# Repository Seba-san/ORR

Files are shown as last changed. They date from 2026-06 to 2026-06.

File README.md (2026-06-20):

# 🌐 Outdoor Radio Robotics (ORR)

> **Módem digital AFSK de código abierto para telemetría robótica sobre transceptores analógicos VHF/UHF en entornos agrícolas con alta densidad de follaje.**

Este repositorio contiene el diseño de *hardware*, el *firmware* embebido y la suite de procesamiento digital de señales de la plataforma **ORR** (*Outdoor Radio Robotics*). El sistema ha sido desarrollado en el **Instituto de Automática (INAUT)** de la **Universidad Nacional de San Juan (UNSJ)** y sirve como material complementario y de validación experimental para posibilitar una comunicación digital de enjambres robóticos e instrumentación en agricultura de precisión.

---

## 📝 Descripción del Proyecto

El despliegue de plataformas robóticas autónomas en entornos agrícolas reales (como olivares o viñedos) enfrenta atenuación electromagnética en las bandas tradicionales de $2.4\text{ GHz}$ o $5.8\text{ GHz}$ debido a la absorción por la biomasa y el follaje húmedo. Para sortear esta limitación física, el proyecto **ORR** propone una arquitectura de acoplamiento no intrusiva que convierte transceptores analógicos de FM comerciales (como el **Baofeng UV-82**) en radio-módems digitales de datos en las bandas de VHF/UHF.

<p align="center">
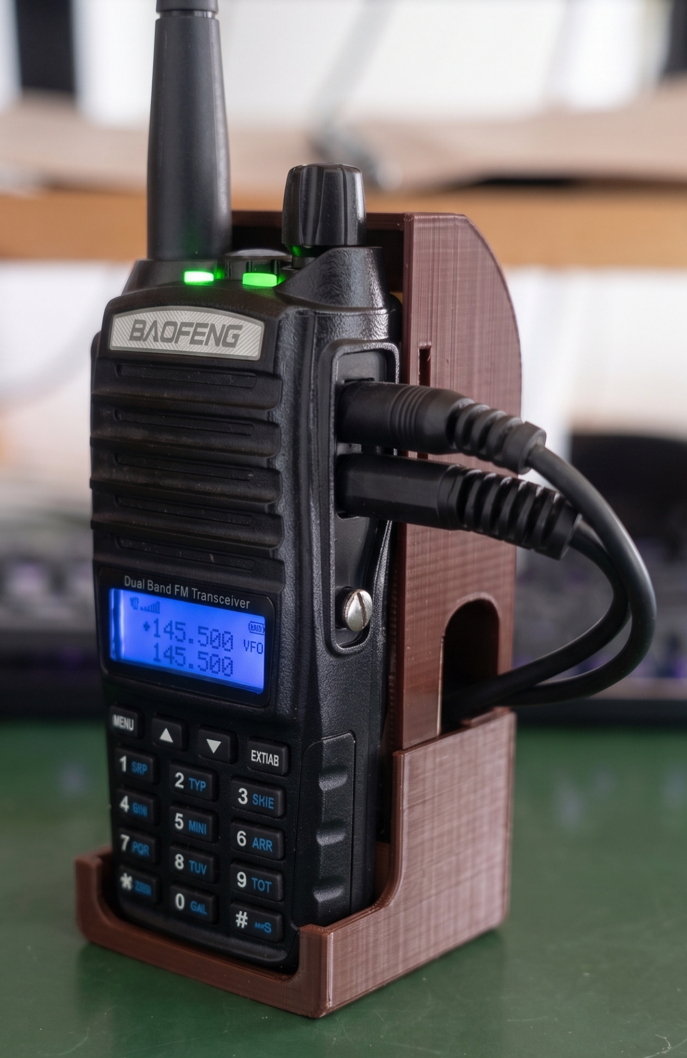
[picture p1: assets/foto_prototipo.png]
Prototipo de radio-módem digital acoplado a transceptor analógico
  
</p>

Mediante el uso de un microcontrolador (**Raspberry Pi Pico 2W**), se implementa un módem AFSK (*Audio Frequency Shift Keying*) a velocidades de hasta 1200 baudios. El sistema se comporta como un bloque físico autónomo que reduce los costos de equipamiento en más de dos órdenes de magnitud respecto a transceptores tácticos industriales.

<p align="center">
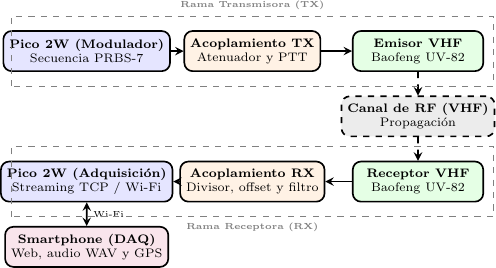
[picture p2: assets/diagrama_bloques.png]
Diagrama de bloques de la arquitectura del sistema ORR
  
</p>

---

## 🛠️ Características Principales

### 1. Acondicionamiento Analógico de *Hardware*
* **Alimentación Unificada:** El microcontrolador se alimenta directamente de la batería de Li-ion del transceptor (7.4 V nominales) mediante un regulador lineal de bajo descarte (LDO), eliminando fuentes de energía secundarias.
* **Aislamiento Galvánico:** Se implementa un aislamiento en la línea de control de transmisión PTT (*Push-To-Talk*) mediante un optoacoplador PC817. Las líneas de audio analógicas emplean un acople AC capacitivo y divisores de tensión específicos para evitar la saturación del amplificador de la radio y proteger las entradas del ADC de la placa Pico 2W.
* **Prevención de Bucles de Masa:** Las masas analógicas y digitales se aíslan en el diseño del conector *jack* de audio, suprimiendo ruidos de conmutación electromagnética que degradarían la relación señal-ruido (SNR).

### 2. Gabinete Mecánico Impreso en 3D
* **Diseño Protector:** Carcasa diseñada para impresión 3D en PLA o PETG que protege la electrónica discreta contra las vibraciones de la maquinaria agrícola.
* **Encastre Antieyección:** Estructura con ranuras específicas que aseguran físicamente el pestillo de liberación de la batería de la radio, previniendo desconexiones accidentales durante el trabajo de campo.

### 3. *Firmware* Embebido (MicroPython)
* **Lazo de Transmisión *Zero-Allocation*:** Síntesis DDS (*Direct Digital Synthesis*) de tonos mediante una tabla de búsqueda (LUT) senoidal precomputada mapeada a PWM de *hardware* a 125 kHz.
* **Supresión de *Jitter*:** Durante la transmisión de tramas (patrones pseudoaleatorios PRBS-7), el recolector de basura (*garbage collector*) se deshabilita temporalmente con `gc.disable()`, asegurando un flujo libre de derivas temporales no deterministas.
* **Protección Térmica Activa:** Máquina de estados finitos que limita la transmisión continua a un máximo de 30 segundos, forzando un ciclo de enfriamiento pasivo equivalente para prolongar la vida útil del paso final de potencia RF de la radio.
* *****Streaming*** Asíncrono Multilazo:** Lectura en tiempo real del ADC a 19.2 kHz mediante *buffers* dobles (*ping-pong*) en el *Core* 1 de la Pico 2W, mientras que el *Core* 0 gestiona un servidor TCP *socket* embebido sobre Wi-Fi para transmitir los datos de forma inalámbrica a la base del operador.

### 4. Demodulador por Envolventes Balanceadas
* **Pipeline Bifurcado por Velocidad:** El pipeline de demodulación se adapta al régimen de baudios detectado.
  - **1200 bd:** Usa filtros `filtfilt` de **fase nula** (*zero-phase*) en las etapas de pasa-banda y pasa-bajos de envolvente, eliminando el retardo de grupo de ~8.8 muestras que causaba ISI sistemático con el método causal clásico. La señal resultante se normaliza geométricamente al rango $[-1, +1]$ usando el punto medio entre percentil 5 y 95 del burst activo, y se aplica un squelch de inicio para evitar el falso enganche del reloj (*false lock*) sobre silencios previos a la ráfaga.
  - **≤ 600 bd:** Usa filtros causales clásicos (`lfilter`), donde el retardo de grupo es despreciable en proporción al período de símbolo.
* **Demodulación por Envolventes Balanceadas:** En ambos casos, las envolventes de amplitud de Mark y Space se compensan con un factor de ganancia dinámica $g$ calculado sobre los percentiles de amplitud del segmento activo: $y = env_{\text{mark}} - g \cdot env_{\text{space}}$.
* **Sincronización DPLL con Grilla Configurable:** La búsqueda de la fase de ráfaga se realiza en una ventana de $1 \times N_s$ muestras (hasta $15 \times N_s$ para 1200 bd), seguida de la sintonización automática del DPLL por grilla sobre los candidatos $K_p$ y $K_i$ definidos en `modules/config.py`. El período de símbolo $N_s = f_s / \text{baud}$ se calcula siempre dinámicamente, sin valores fijos por velocidad.
* **Métrica de Confianza ($C_k$):** Cálculo analítico de la diferencia relativa entre las envolventes balanceadas de Mark y Space en cada instante de muestreo, lo que permite evaluar la calidad del bit recuperado directamente en la etapa de decisión.

---

## 📈 Ensayos y Resultados Experimentales

Para validar el desempeño del módem AFSK y el enlace de radiofrecuencia en condiciones de operación reales, se diseñó y ejecutó una campaña experimental dividida en **dos entornos de ensayo diferenciados** (2 experimentos independientes):

1. **Espacio Abierto (Libre):** Ensayo en línea de vista rural libre de obstáculos y follaje. Sirve como canal de calibración y referencia para evaluar el desempeño básico y el límite térmico/frecuencial del enlace.
2. **Bajo Follaje de Olivos (Campo):** Ensayo realizado en una plantación densa de olivos en la provincia de San Juan, Argentina. El enlace se caracterizó por la total obstrucción de la línea de vista directa debido a la biomasa frutal, con las radios posicionadas a menos de 1 metro del suelo y las antenas polarizadas horizontalmente para evitar la absorción de los troncos verticales.

Ambos experimentos operaron a una potencia de **1.0 W** (Low Power) en la banda UHF a **433 MHz**.

### 1. Entornos de Ensayo

La siguiente ilustración muestra las condiciones físicas de ambos escenarios de medición:

<p align="center">
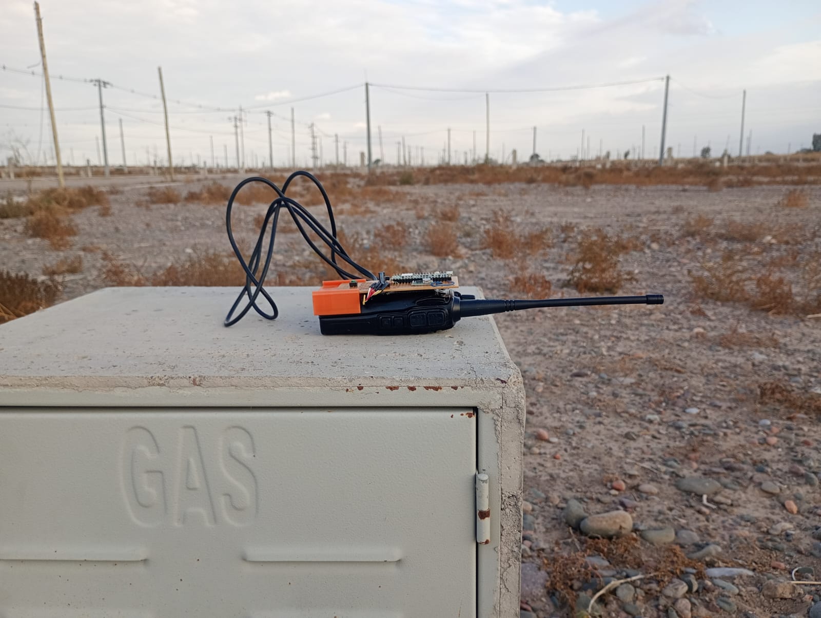
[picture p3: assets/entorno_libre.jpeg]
Entorno del ensayo en espacio abierto (Libre)
  
  Entorno del ensayo bajo follaje de olivos (Campo)
</p>

### 2. Georreferenciación de Mediciones (Figura 5 del Paper)

Los puntos específicos de medición, capturados y georreferenciados mediante el Web-DAQ en el teléfono celular del operador, se ubican a distancias nominales de **5 m, 500 m, 1000 m y 1500 m** en la plantación:

<p align="center">
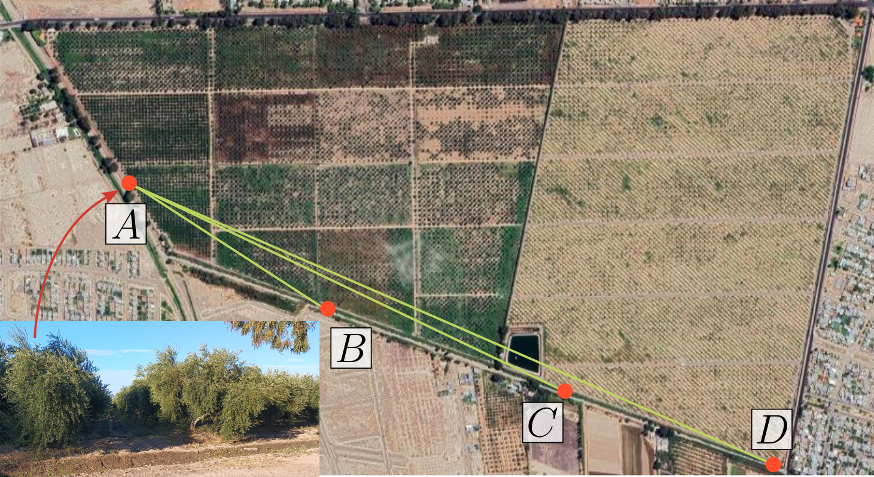
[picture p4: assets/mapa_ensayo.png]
Mapa de puntos de ensayo y geolocalización de las mediciones
  
</p>

### 3. Tasa de Error de Bit (BER)

A continuación se consolidan los resultados de la Tasa de Error de Bit (BER %) obtenidos en cada entorno para las diferentes distancias reales y regímenes de velocidad (baudrate) analizados:

#### Experimento 1: Espacio Abierto (Libre)
| Distancia Real (Nominal) | 10 bd | 50 bd | 150 bd | 300 bd | 600 bd | 1200 bd |
| :---: | :---: | :---: | :---: | :---: | :---: | :---: |
| **0 m** (5 m) | 0.00% | 0.00% | 0.36% | 0.03% | 0.06% | 5.39% |
| **552 m** (500 m) | 0.00% | 0.08% | 0.05% | 0.04% | 0.06% | 5.80% |
| **985 m** (1000 m) | 0.00% | 0.08% | 0.02% | 0.04% | 0.13% | 11.20% |
| **1382 m** (1500 m) | 0.00% | 0.04% | 0.06% | 0.02% | 0.06% | 5.80% |

#### Experimento 2: Bajo Follaje de Olivos (Campo)
| Distancia Real (Nominal) | 10 bd | 50 bd | 150 bd | 300 bd | 600 bd | 1200 bd |
| :---: | :---: | :---: | :---: | :---: | :---: | :---: |
| **0 m** (5 m) | 0.00% | 4.69% | 0.08% | 0.03% | 0.05% | 5.49% |
| **549 m** (500 m) | 0.00% | 0.04% | 0.05% | 0.04% | 0.51% | 5.40% |
| **1071 m** (1000 m) | 0.00% | 0.00% | 0.03% | 0.05% | 0.06% | 5.46% |
| **1484 m** (1500 m) | 0.00% | 0.04% | 0.03% | 0.02% | 0.03% | 6.33% |

El comportamiento y la comparación visual del BER de ambos entornos se detalla en las curvas experimentales (subplots) obtenidas:

<p align="center">
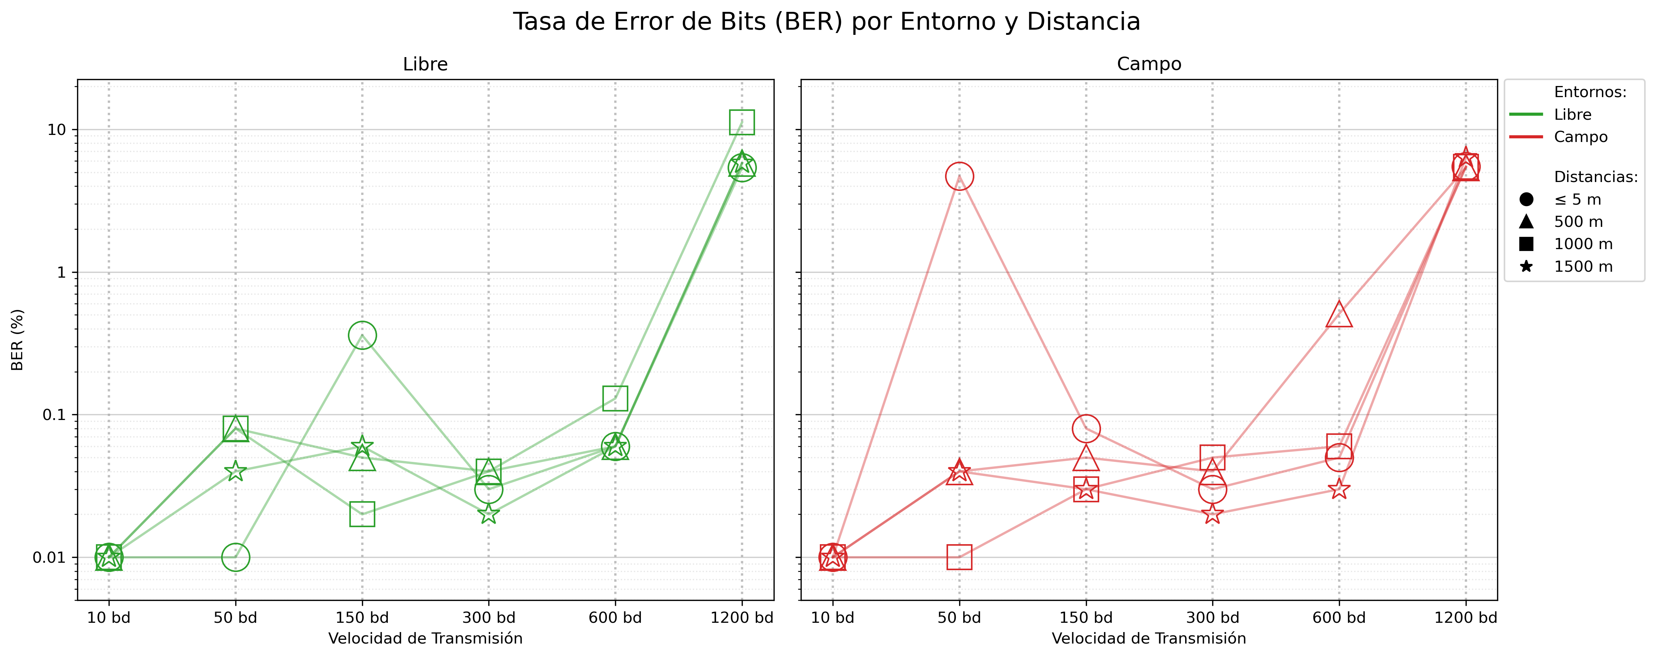
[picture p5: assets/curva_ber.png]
Curvas experimentales de tasa de errores de bit (BER) vs velocidad y distancia
  
</p>

---

## 💾 Dataset Experimental y Bases de Datos

Las campañas de medición en campo y laboratorio produjeron un conjunto de datos (*dataset*) de señales de audio digitalizadas y telemetría de geolocalización. Debido al volumen y al tamaño de los archivos de audio crudos (`.wav`), el dataset completo está almacenado en un repositorio compartido externo.

* 🔗 **Acceso al Dataset Completo (Google Drive):** [Bases de Datos de Audio ORR](https://drive.google.com/drive/folders/1wKw8cH1Ox6S6E19gmR8-GltFr6CDUwmw?usp=sharing)
* 📖 **Descripción Detallada:** Para una explicación completa sobre la secuencia pseudoaleatoria PRBS-7, el hardware de adquisición Web-DAQ (Core 1 para ADC y Core 0 para Wi-Fi/streaming), las velocidades ensayadas, el significado de los nombres de los archivos y la distribución de las carpetas, consulte la [Guía Detallada del Dataset](./data/README.md).

---

## 📂 Estructura de Directorios

El repositorio se organiza de la siguiente manera:

```
ORR/
├── assets/              # Imágenes y recursos visuales para la documentación
├── data/                # Dataset experimental (archivos CSV con metadatos GPS e instruciones de audio)
├── firmware/            # Código fuente para Raspberry Pi Pico 2W (MicroPython)
│   ├── tx/              # Firmware del nodo transmisor (DDS, PWM, FSM, PRBS-7)
│   └── rx/              # Firmware del nodo receptor (adquisición en Core 1, servidor TCP en Core 0)
├── fotos/               # Fotografías de los entornos experimentales (libre y campo)
├── hardware/            # Esquemáticos y manual de acondicionamiento de la interfaz analógica
│   └── esquematicos/    # Circuitos y pinout de interconexión
├── mechanics/           # Gabinete protector e interfaz de acople mecánico 3D (STL/STEP)
└── processing/          # Suite de demodulación *offline* en Python (Envolventes, Búsqueda de Fase, BER) y MATLAB
```

---

## 🚀 Cómo Empezar

### Requisitos Previos
* ***Hardware***:
  * Raspberry Pi Pico 2W (o Pico W estándar).
  * Transceptor analógico FM Baofeng UV-82 (o similar con conector tipo Kenwood de dos pines).
  * Componentes discretos detallados en los esquemáticos de la carpeta `hardware/`.
* **Software:**
  * MicroPython v1.20 o superior instalado en el microcontrolador.
  * Suite de demodulación: Python 3.10+ con las librerías indicadas en [processing/requirements.txt](./processing/requirements.txt).

Para instrucciones detalladas de implementación de cada módulo, por favor consulta los archivos `README.md` y guías específicos dentro de cada directorio:
* Ver [firmware/README.md](./firmware/README.md) para la configuración del microcontrolador.
* Ver [hardware/README.md](./hardware/README.md) para el circuito de acoplamiento analógico.
* Ver [processing/README.md](./processing/README.md) para la suite de demodulación espectral y cálculo de BER.
* Ver [processing/workflow_bursts.md](./processing/workflow_bursts.md) para el flujo de trabajo integrado y segmentación automática de ráfagas.
* Ver [data/README.md](./data/README.md) para acceder a los metadatos de GPS y descargar el dataset de audio.

---

## 🎓 Créditos y Citación

Este desarrollo forma parte de la línea de investigación en redes tolerantes a retardos (DTN) aplicadas a la robótica agrícola del **INAUT (UNSJ)**.

Si utiliza este trabajo en su investigación o desarrollo, por favor cite el artículo científico asociado:

```bibtex
@inproceedings{sansoni2026orr,
  author    = {Sansoni, Sebastian},
  title     = {Diseño y Análisis de un sistema de Comunicación Digital sobre Radios Analógicas para Robótica en exteriores},
  booktitle = {Actas de las Jornadas Argentinas de Robótica (JAR)},
  year      = {2026},
  address   = {San Juan, Argentina}
}
```

---

## ⚖️ Licencia

Este proyecto está bajo la licencia **Apache 2.0**. Esto significa que es **código abierto** y libre para cualquier uso (incluyendo comercial, modificación y distribución), con las siguientes garantías clave:
* **Protección de Patentes:** Evita litigios de patentes entre colaboradores y usuarios.
* **Respeto de Marca:** Protege el nombre del proyecto (*Outdoor Radio Robotics*) e institucional (INAUT/UNSJ) frente a usos no autorizados de terceros en software derivado.

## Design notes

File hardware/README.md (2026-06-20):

# 🛠️ Acondicionamiento Analógico y Hardware (Front-End)

El acoplamiento físico entre la Raspberry Pi Pico 2W y la radio analógica **Baofeng UV-82** se realiza de forma externa y no intrusiva a través del conector tipo Kenwood de 2 pines (*jack* de 3.5 mm para audio/parlante y *jack* de 2.5 mm para micrófono/PTT). 

Este directorio recopila las especificaciones de diseño, cálculos analógicos y diagramas esquemáticos para reproducir la interfaz física.

---

## 📌 Conector Kenwood y Distribución de Colores

Para evitar falsos contactos y ruidos analógicos inducidos por soldaduras deficientes, se utiliza un cable comercial premoldeado Kenwood cortado a la mitad. Los colores internos del conductor típicamente corresponden a las siguientes conexiones:

```
               [ PLUG 3.5 mm ]                     [ PLUG 2.5 mm ]
               (Parlante / RX)                     (Micrófono / TX)
               
                 .-.                                 .-.
                |   | Punta (Rojo): +Speaker        |   | Punta (Rojo): -Mic / PTT1
                |===|                               |===|
                |   | Anillo (Amarillo): Tx Data    |   | Anillo (Amarillo): +Mic
                |===|                               |===|
                |   | Base (Blanco): GND/Shield     |   | Base (Blanco): GND/PTT Base
                `---'                               `---'
```

---

## 📻 1. Circuito de Transmisión (Front-End TX) y Control PTT

El circuito transmisor acondiciona la señal digital de audio generada por PWM del microcontrolador y gobierna el pulsador *Push-To-Talk* (PTT) de la radio mediante aislamiento óptico.

### Diagrama Esquemático

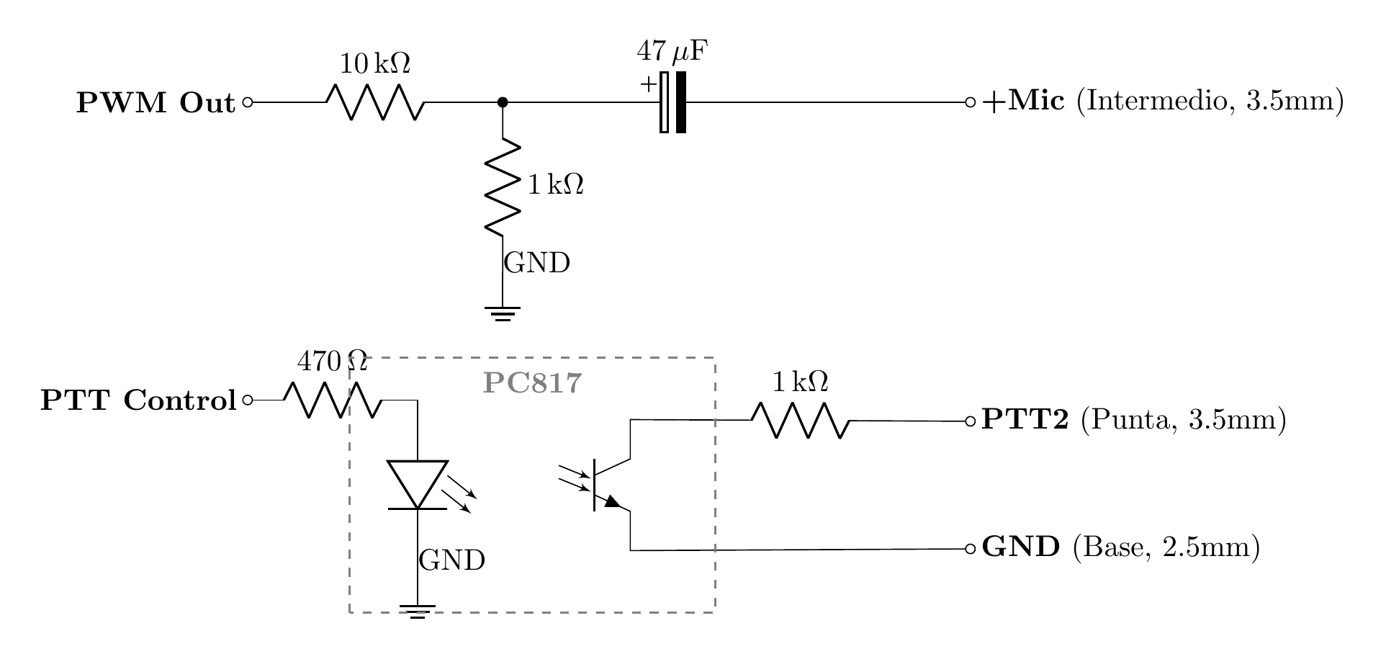
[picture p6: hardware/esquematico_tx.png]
Esquema de acondicionamiento de transmisión (TX) y aislamiento galvánico de la línea PTT


### Explicación del Diseño y Cálculos
1. **Atenuación Resistiva (Divisor L):** La señal PWM sintetizada por el pin `GP17` oscila en un rango digital de 0 a 3.3 V pico a pico. Para no saturar el amplificador de entrada de micrófono de la radio (diseñado para niveles de voz de ~10-30 mV), el divisor resistivo ($R_1 = 10\text{ k}\Omega$, $R_2 = 1\text{ k}\Omega$) atenúa la señal en un factor de:
   $$Av = \frac{R_2}{R_1 + R_2} = \frac{1\text{ k}\Omega}{10\text{ k}\Omega + 1\text{ k}\Omega} \approx 0.091\text{ (i.e., } -20.8\text{ dB)}$$
   Esto reduce la señal a $\approx 300\text{ mV}_{\text{p-p}}$ en el nodo intermedio, previniendo recortes armónicos.
2. **Bloqueo de Tensión Continua (C1):** Un capacitor electrolítico de $47\,\mu\text{F}$ en serie bloquea la componente continua de la Pico 2W. Junto con la impedancia de entrada de la radio ($R_{\text{mic}} \approx 2\text{ k}\Omega$), forma un filtro paso alto con frecuencia de corte:
   $$f_c = \frac{1}{2\pi R_{\text{mic}} C_1} = \frac{1}{2\pi \cdot 2000\,\Omega \cdot 47\,\mu\text{F}} \approx 1.69\text{ Hz}$$
   Esto asegura una respuesta plana para las frecuencias de audio AFSK ($1200\text{ Hz}$ y $2400\text{ Hz}$).
3. **Aislamiento Galvánico del PTT:** Para transmitir, la radio requiere unir físicamente la línea de micrófono con masa. Para no cortocircuitar o introducir ruido del plano digital del microcontrolador al transmisor de RF, se implementa un optoacoplador **PC817**. El pin digital `GP16` enciende el LED interno (limitado por $R_3 = 470\,\Omega$), el cual satura el fototransistor interno para cerrar el circuito PTT de la radio de forma aislada.

---

## 🎧 2. Circuito de Recepción (Front-End RX)

El circuito adaptador del receptor reduce los altos niveles de tensión del altavoz analógico de la radio y los centra en el rango dinámico unipolar (0 a 3.3 V) de la entrada analógica `GP26 (ADC0)` del microcontrolador.

### Diagrama Esquemático

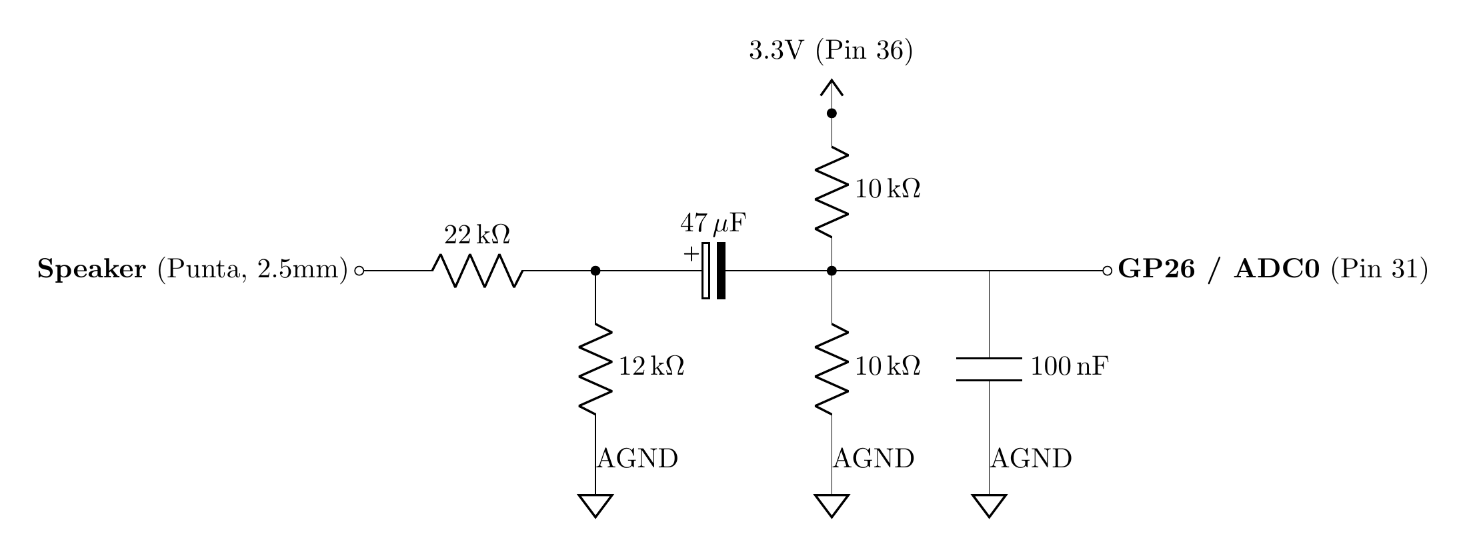
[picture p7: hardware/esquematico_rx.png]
Esquema del Front-End Analógico de Recepción


### Explicación del Diseño y Cálculos
1. **Atenuador de Entrada (R4, R5):** El volumen máximo de salida del altavoz de la radio puede superar los 5 V pico a pico, lo que dañaría la entrada del ADC. El divisor compuesto por $R_4 = 22\text{ k}\Omega$ y $R_5 = 12\text{ k}\Omega$ atenúa la señal analógica multiplicándola por un factor de $0.35$ ($\approx 1.76\text{ V}_{\text{p-p}}$ máximo), garantizando un margen seguro.
2. **Acoplamiento AC (C2):** Un capacitor electrolítico de $47\,\mu\text{F}$ en serie elimina el nivel de continua original de la etapa amplificadora de audio de la radio.
   * La resistencia de fuente equivalente es $R_s = R_4 \parallel R_5 \approx 7.76\text{ k}\Omega$.
   * La resistencia de polarización es $R_{\text{bias}} = R_6 \parallel R_7 = 5\text{ k}\Omega$.
   * La frecuencia de corte del filtro paso alto resultante es:
     $$f_c = \frac{1}{2\pi (R_s + R_{\text{bias}}) C_2} = \frac{1}{2\pi \cdot (7760\,\Omega + 5000\,\Omega) \cdot 47\,\mu\text{F}} \approx 0.265\text{ Hz}$$
     Esta frecuencia de corte garantiza que la señal analógica entre al ADC libre de distorsiones de fase temporales.
3. **Red de **Offset** (R6, R7):** El ADC de la Pico lee tensiones de $0$ a $3.3\text{ V}$. Para poder digitalizar el semiciclo negativo de la onda senoidal de audio sin recorte, el divisor resistivo simétrico de dos resistencias de $10\text{ k}\Omega$ inyecta un desplazamiento continuo de exactamente **$1.65\text{ V}$** (mitad del rango del ADC).
4. **Filtro de Ruido de Referencia (C3):** Un capacitor cerámico de $100\text{ nF}$ en paralelo con $R_7$ desacopla armónicos de alta frecuencia y ruidos de conmutación del bus digital de alimentación de 3.3 V, estabilizando la referencia analógica del ADC.

---

## ⚠️ Advertencia Crítica de Bucles de Tierra

> [!CAUTION]
> **COMPARTIR BATERÍA EXIGE MASA DE AUDIO AISLADA:**
> Si la Raspberry Pi Pico 2W y la radio Baofeng UV-82 se alimentan unificadamente de la misma batería (7.4 V de la radio adaptados a la Pico), ambos equipos ya poseen una referencia común a través de la masa de alimentación. 
> 
> En esta condición, **bajo ningún concepto se debe soldar el cable de masa del *jack* de 3.5 mm / 2.5 mm a la masa digital (GND) del microcontrolador**. Si se realiza esta conexión secundaria, se cierra un lazo inductivo que reduce la relación señal-ruido (SNR) del ADC e introduce un zumbido de clicks en el audio analógico, aumentando la tasa de errores de bit (BER).

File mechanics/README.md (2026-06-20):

# 🖨️ Gabinete Mecánico 3D y Acoplamiento

Este directorio está reservado para los modelos tridimensionales (archivos `.stl`, `.step` / `.stp`) de la carcasa de protección y acople mecánico del módem ORR con la radio Baofeng UV-82.

---

## 🛠️ Características de Diseño

El diseño del gabinete ha sido desarrollado considerando las condiciones de vibración y humedad del trabajo agrícola en el campo:

1. **Dimensiones Extendidas:** La carcasa se ha alargado físicamente para alojar de forma holgada tanto la placa transmisora (TX) como la receptora (RX) con sus componentes discretos. Esto evita tensiones mecánicas internas o desprendimiento de soldaduras.
2. **Protector de Pestillo de Batería:** Se integran encastres y ranuras protectoras para el botón de liberación de la batería del Baofeng UV-82. Esto previene que el módulo digital presione accidentalmente el mecanismo de eyección y provoque que la batería se desprenda ante sacudidas o golpes en tractores agrícolas.
3. **Puntos de Alivio de Tensión:** Cuenta con pasacables con curvas diseñadas para evitar fatiga en los conectores de audio de 3.5 mm y 2.5 mm.

---

## ⚙️ Parámetros de Impresión Recomendados

Para garantizar la durabilidad a la intemperie y resistencia a la radiación solar en cultivos agrícolas, se sugieren los siguientes parámetros:

* **Material:** **PLA** o **PETG** (seleccionados de acuerdo a la facilidad de impresión y la tolerancia térmica requerida).
* **Altura de Capa:** $0.2\text{ mm}$ o $0.15\text{ mm}$ para un encastre preciso.
* **Relleno (Infill):** $25\text{ a } 35\%$ con patrón giroidal (*gyroid*) o rejilla para maximizar la resistencia a impactos.
* **Perímetros (Muros):** Mínimo 3 de espesor.
* **Soportes:** No requiere soportes si se orienta de forma plana sobre la base (según el diseño de encastres).

---

## 📂 Archivos de Diseño 3D en esta carpeta

Este directorio contiene las piezas del diseño final de la carcasa, listas para imprimir o editar:

*   **[base_v4-carcasa.stl](./base_v4-carcasa.stl)**: Pieza principal del gabinete de protección (carcasa).
*   **[base_v3-base_con_placa.stl](./base_v3-base_con_placa.stl)**: Base de acoplamiento que sostiene mecánicamente la electrónica y las placas.
*   **[lengueta.stl](./lengueta.stl)**: Pestillo o lengüeta de traba para fijar el ensamble al seguro de la radio.
*   **[base_v4.FCStd](./base_v4.FCStd)**: Archivo de diseño paramétrico original creado en **FreeCAD** (herramienta de CAD de código abierto). Contiene todo el historial de modelado para realizar modificaciones, redimensionados o adaptaciones futuras.

---

## 📷 Previsualización del Ensamble y Piezas

A continuación se muestran capturas de pantalla de los modelos mecánicos exportados directamente desde **FreeCAD** para facilitar la comprensión de las piezas y el ensamble final con la radio:

| Ensamble Completo con Radio | Ensamble de Piezas de Carcasa |
| :---: | :---: |
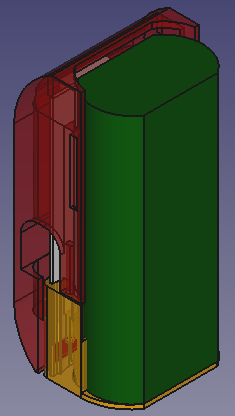
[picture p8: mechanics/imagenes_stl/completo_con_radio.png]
Ensamble Completo con Radio Baofeng
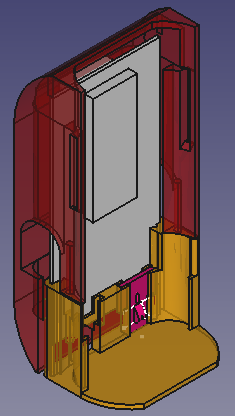
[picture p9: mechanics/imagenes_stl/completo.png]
Ensamble de la Carcasa Cerrada
|  |  |
| **Placa Base y Lengüeta de Traba** | |
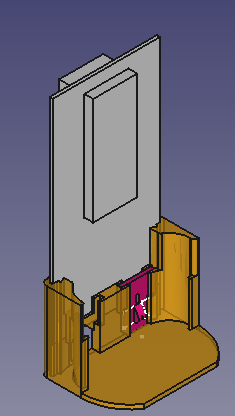
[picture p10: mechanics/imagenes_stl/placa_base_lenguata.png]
Placa Base y Lengüeta
|  | |

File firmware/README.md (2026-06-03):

# 💾 Firmware Embebido: Módem AFSK para Raspberry Pi Pico 2W

Esta carpeta contiene el firmware en **MicroPython** desarrollado para los nodos Transmisor (TX) y Receptor (RX) del sistema de comunicación digital ORR, ejecutados en microcontroladores Raspberry Pi Pico 2W (basados en el chip RP2350).

---

## 🛠️ Requisitos Previos e Instalación

### 1. Cargar MicroPython
Ambos microcontroladores deben tener instalado **MicroPython v1.20** o superior.
1. Descarga el firmware oficial `.uf2` para la Raspberry Pi Pico 2W/W desde [micropython.org](https://micropython.org/download/RPI_PICO2W/).
2. Conecta la placa a la computadora por USB manteniendo presionado el botón **BOOTSEL**.
3. Suelta el botón una vez que la placa aparezca como una unidad de almacenamiento masivo llamada `RPI-RP2` (o similar).
4. Arrastra y suelta el archivo `.uf2` dentro de la unidad. El dispositivo se reiniciará automáticamente corriendo MicroPython.

### 2. Cargar los Archivos
Utiliza un IDE compatible como **Thonny** o herramientas de línea de comandos como `mpremote` para transferir los archivos:
* **Para el Transmisor:** Carga todos los archivos de la carpeta [tx/](./tx) en la raíz de la memoria flash del microcontrolador.
* **Para el Receptor:** Carga todos los archivos de la carpeta [rx/](./rx) en la raíz de la memoria flash del microcontrolador.

---

## 📌 Mapeo de Pines de la Raspberry Pi Pico 2W

Las interfaces se han estandarizado sobre las siguientes conexiones físicas de la placa:

| Pin Físico | Pin Lógico | Función en el Sistema | Conexión Externa Asociada |
| :---: | :---: | :--- | :--- |
| **Pin 4** | `GP2` | Entrada Digital (Pulsador) | Pulsador de activación (Gatillo) a tierra (`GND`) |
| **Pin 22** | `GP17` | Salida de Audio PWM (TX) | Entrada al Atenuador analógico de Transmisión (Mic) |
| **Pin 21** | `GP16` | Control Digital PTT | Entrada del Optoacoplador PC817 (Pin 1 - Ánodo) |
| **Pin 23** | `GND` | Tierra Digital | Entrada del Optoacoplador PC817 (Pin 2 - Cátodo) |
| **Pin 31** | `GP26` | Entrada de Adquisición ADC (RX) | Salida del circuito Front-End Analógico (AFE) |
| **Pin 33** | `AGND` | Tierra Analógica | Referencia del circuito Front-End Analógico (AFE) |
| **Pin 36** | `3V3_OUT` | Alimentación de Referencia | Red de polarización resistiva del Front-End (Offset) |

> [!WARNING]
> **PREVENCIÓN DE BUCLES DE TIERRA:**
> Al compartir la alimentación directa de la batería del transceptor, el microcontrolador y la radio poseen una referencia de masa común. Por lo tanto, **bajo ningún concepto se debe conectar el pin de masa (GND) del conector *jack* de audio a la masa digital de la placa Pico 2W**. De realizar esta conexión secundaria, se creará un bucle de tierra cerrado inductivo que inyectará zumbidos electromagnéticos en el receptor, aumentando la tasa de errores de bit y pudiendo ocasionar daños físicos por corrientes de retorno de RF.

---

## 🚀 Instrucciones de Operación

### 1. Transmisor (TX)
El firmware del transmisor sintetiza tonos AFSK puros mediante el periférico PWM por hardware a 125 kHz utilizando una tabla de búsqueda senoidal de 256 muestras precomputada para anular la latencia y fluctuaciones temporales (*jitter*) inducidas por el recolector de basura de MicroPython.

* Al alimentar el nodo TX, este ingresa en modo de espera.
* Al presionar el botón físico en `GP2` (Gatillo), el transmisor inicia una ráfaga:
  1. Activa el pin `GP16` para cerrar el circuito PTT a través del optoacoplador, encendiendo la transmisión de la radio.
  2. Genera una portadora en vacío durante un retardo de preámbulo configurable para compensar la latencia de apertura del circuito silenciador (*squelch*) del receptor.
  3. Sintetiza y transmite cíclicamente el patrón pseudoaleatorio de bits **PRBS-7** generado por el registro de desplazamiento con retroalimentación lineal ($y(n) = y(n-6) \oplus y(n-7)$). El volumen de datos se adapta automáticamente a la velocidad configurada.
  4. Finaliza con un retardo de cola y apaga el pin `GP16` (PTT) para retornar al modo de escucha.
  5. **Protección Térmica:** La máquina de estados bloquea el gatillo y obliga a un periodo de enfriamiento ininterrumpido igual al 100% de la duración de la transmisión para proteger el amplificador final de RF de la radio Baofeng.

### 2. Receptor (RX) y Interfaz Web-DAQ
El receptor actúa como un digitalizador analógico inalámbrico.
* Al encender el receptor, este levanta un **Punto de Acceso Wi-Fi** local con las siguientes credenciales:
  * **SSID:** `PicoSDR`
  * **Contraseña:** `sdrpassword`
  * **IP del Servidor:** `192.168.4.1`
* El operador de campo se conecta a esta red con su teléfono inteligente y accede a la dirección web `http://192.168.4.1` en su navegador.
* La interfaz de control **Web-DAQ** (ejecutada mediante JavaScript en el navegador del cliente) realiza las siguientes tareas de forma asíncrona:
  1. Se conecta al endpoint `/stream` del *socket* TCP de la Pico.
  2. En Core 1 de la Pico, las interrupciones del Timer leen el ADC GP26 a una tasa constante de **19.2 kHz** y depositan los datos en un esquema de doble *buffer* (*ping-pong*) de 19,200 muestras firmadas de 16 bits.
  3. En Core 0 de la Pico, el servidor web realiza un *streaming* binario continuo de estos bloques hacia el celular.
  4. El script en JavaScript almacena los bloques en RAM y graba concurrentemente los metadatos de posicionamiento GPS del celular en tiempo real.
  5. Al pulsar "Detener", el navegador concatena los bloques de audio, les inyecta una **cabecera estándar RIFF/WAVE de 44 bytes** y genera la descarga de un archivo `.wav` sin comprimir (19200 Hz, Mono, 16-bit signed) y un archivo de telemetría `.csv` indexado con la ubicación exacta del ensayo.

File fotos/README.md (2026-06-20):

# 📸 Galería Fotográfica de los Ensayos Experimentales

Este directorio contiene el registro fotográfico tomado durante las campañas de medición en exteriores para el proyecto **ORR** en la provincia de San Juan, Argentina.

Las imágenes están organizadas en dos carpetas según el entorno físico del experimento:
1. **Bajo Follaje de Olivos (`fotos/campo/`):** Ensayos con severa obstrucción de biomasa frutal.
2. **Espacio Abierto (`fotos/libre/`):** Canal de calibración en línea de vista despejada.

---

## 🌳 Experimento: Bajo Follaje de Olivos (Campo)

Mediciones realizadas dentro de una plantación intensiva de olivos. La antena y el módem se posicionaron bajo el follaje denso para evaluar la difracción y atenuación de la banda en VHF/UHF frente a la biomasa húmeda.

| Foto 1 | Foto 2 |
| :---: | :---: |
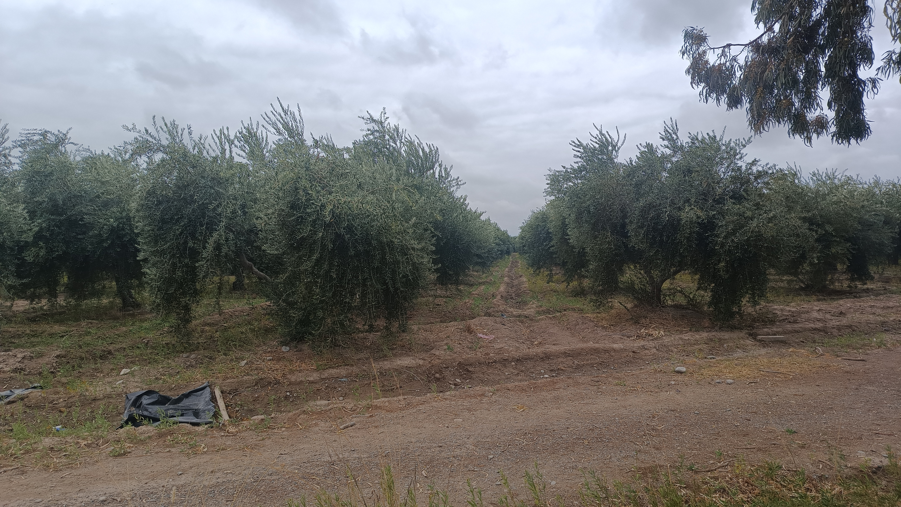
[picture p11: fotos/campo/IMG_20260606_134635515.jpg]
Montaje del módem y radio en el árbol
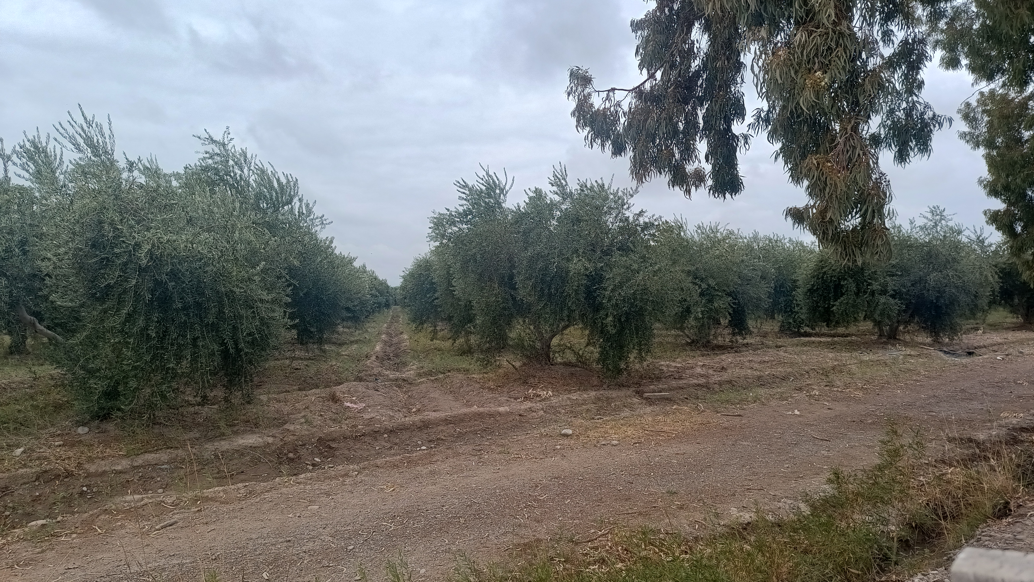
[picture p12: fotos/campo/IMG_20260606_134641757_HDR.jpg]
Detalle del cableado y antena en el olivar
|  |  |
| `IMG_20260606_134635515.jpg` | `IMG_20260606_134641757_HDR.jpg` |
| **Foto 3** | **Foto 4** |
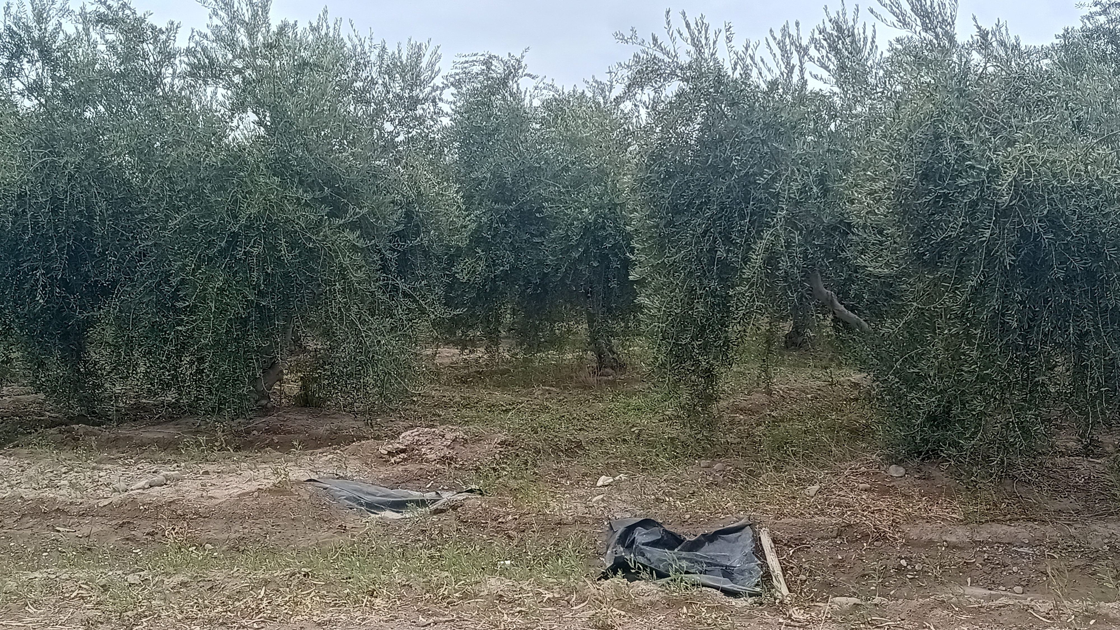
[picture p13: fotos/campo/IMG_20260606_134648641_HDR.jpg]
Entorno densamente arbolado de los ensayos
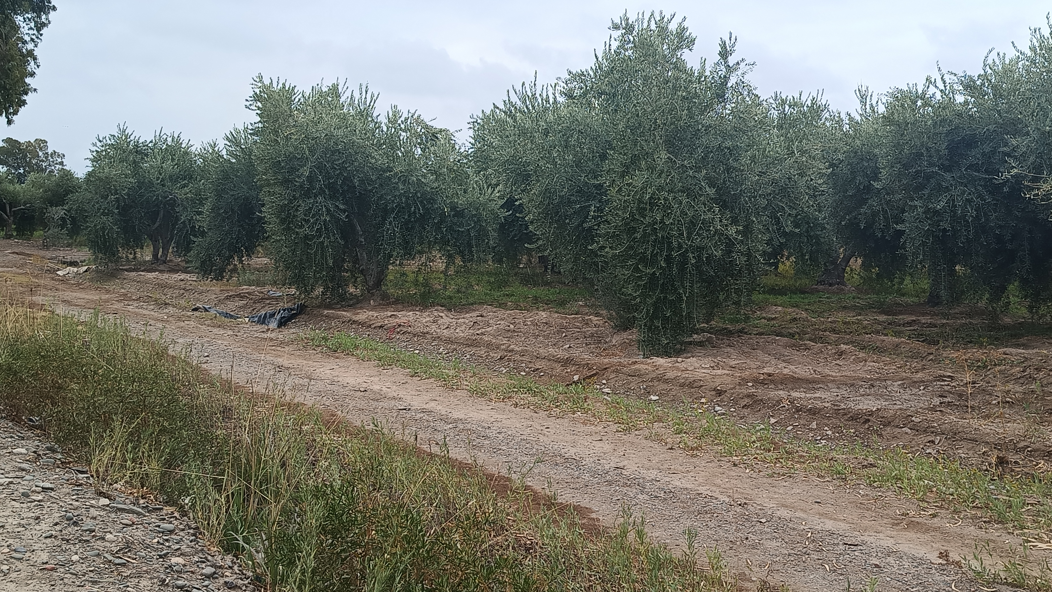
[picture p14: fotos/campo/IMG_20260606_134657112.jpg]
Ubicación y fijación del equipo
|  |  |
| `IMG_20260606_134648641_HDR.jpg` | `IMG_20260606_134657112.jpg` |

---

## 🌾 Experimento: Espacio Abierto (Libre)

Mediciones de control a campo abierto en un camino rural despejado, sin obstrucción de follaje, para establecer una referencia ideal de tasa de error de bit (BER) base y calibración de los transceptores.

| Foto 1 | Foto 2 |
| :---: | :---: |
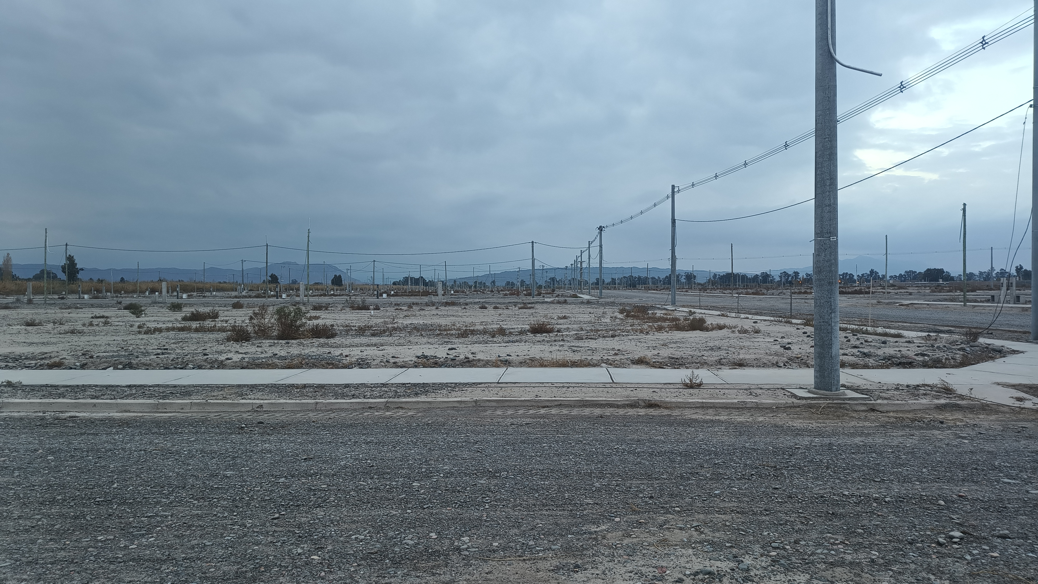
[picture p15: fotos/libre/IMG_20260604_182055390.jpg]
Trípode y radio en el punto de transmisión
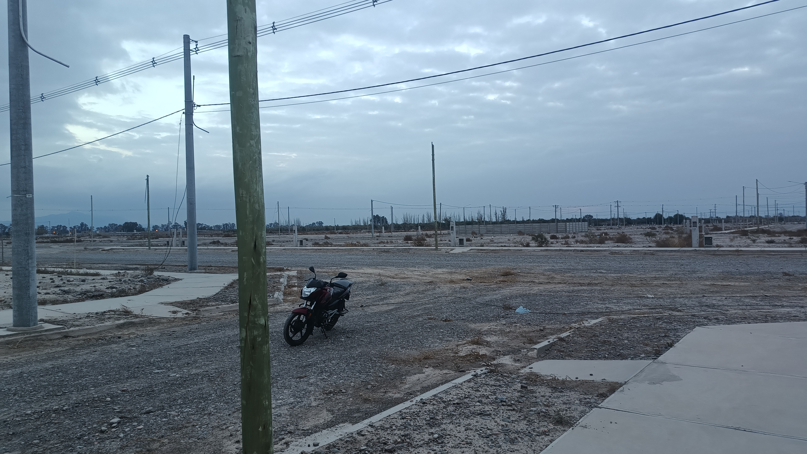
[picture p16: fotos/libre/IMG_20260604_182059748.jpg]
Preparativos del enlace de radio
|  |  |
| `IMG_20260604_182055390.jpg` | `IMG_20260604_182059748.jpg` |
| **Foto 3** | **Foto 4** |
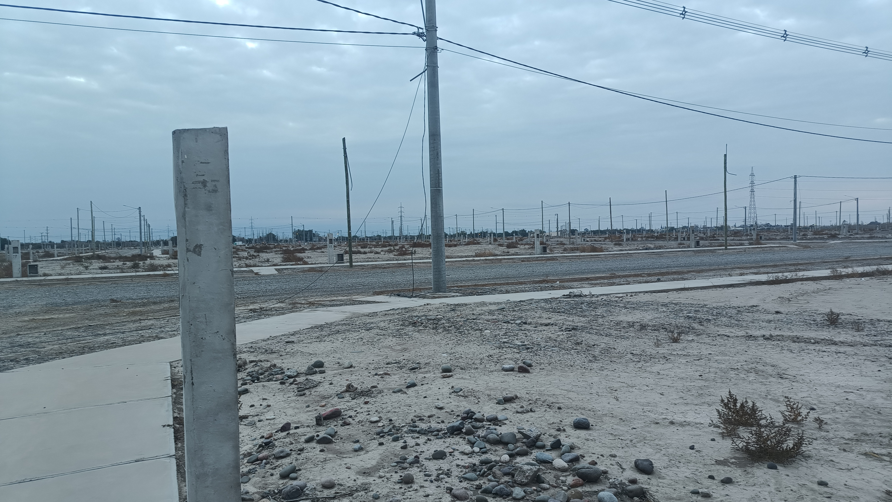
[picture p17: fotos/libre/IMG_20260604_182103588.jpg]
Montaje del transceptor a campo abierto
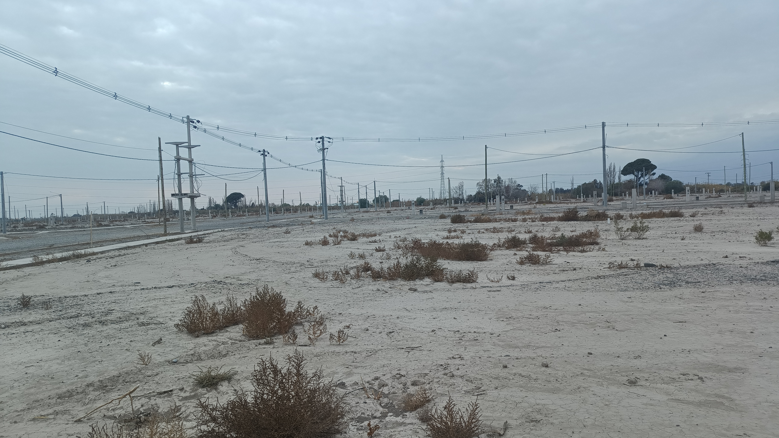
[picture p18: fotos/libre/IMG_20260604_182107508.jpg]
Medidor de señal y radio receptor
|  |  |
| `IMG_20260604_182103588.jpg` | `IMG_20260604_182107508.jpg` |
| **Foto 5** | **Foto 6** |
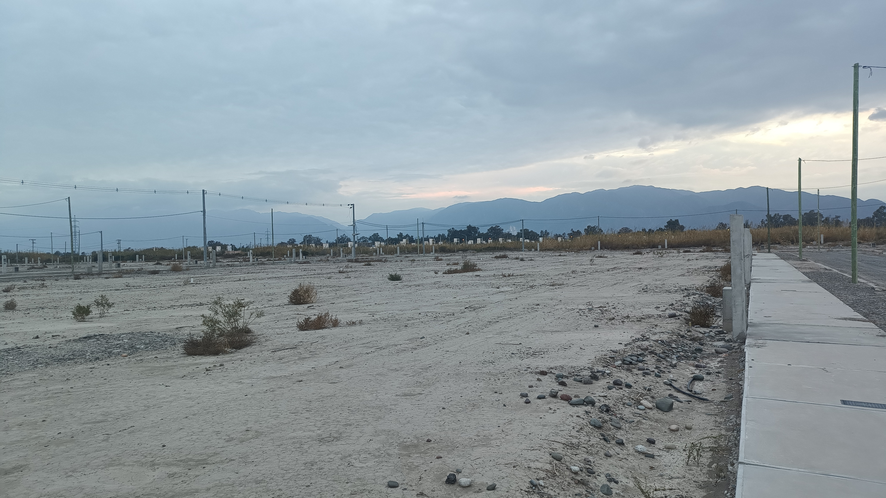
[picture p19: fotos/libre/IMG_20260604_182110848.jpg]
Acondicionamiento y detalles físicos de la instalación
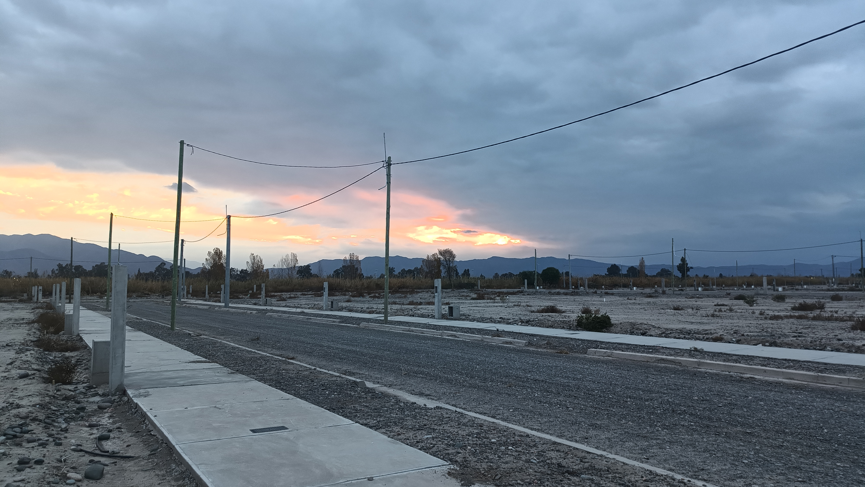
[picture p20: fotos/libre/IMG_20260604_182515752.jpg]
Operador registrando datos
|  |  |
| `IMG_20260604_182110848.jpg` | `IMG_20260604_182515752.jpg` |
| **Foto 7** | **Entorno Despejado** |
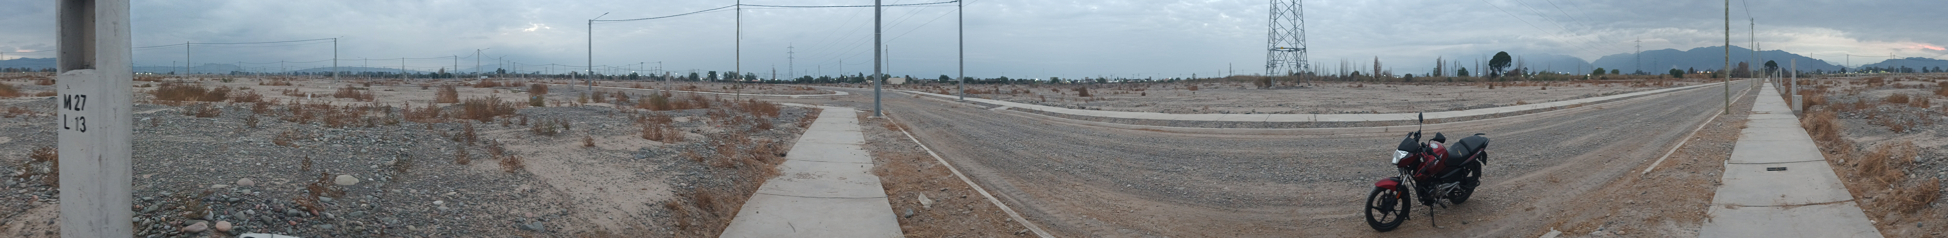
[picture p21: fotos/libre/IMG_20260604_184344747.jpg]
Equipo receptor con vista directa despejada
|  | Panorámica del camino rural |
| `IMG_20260604_184344747.jpg` | `libre.jpeg` |

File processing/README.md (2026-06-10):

# 📊 Suite de Procesamiento y Demodulación *Offline*

Esta carpeta contiene la suite de herramientas desarrolladas en **Python** para la demodulación síncrona *offline* y la caracterización espectral de las señales de audio AFSK capturadas por el Web-DAQ.

---

## 🚀 Flujo del Procesamiento Digital de Señales (DSP)

El software realiza el procesamiento en seis etapas secuenciales de bajo nivel. A partir del paso 3, el pipeline se **bifurca** según la velocidad de símbolo detectada para compensar las características específicas de cada régimen de baudios:

```
                  +-----------------------------------+
                  |      Archivo WAV de Entrada       |
                  +-----------------------------------+
                                    │
                                    ▼
                  +-----------------------------------+
                  |  Filtro FIR Kaiser (300-3000 Hz)  |
                  +-----------------------------------+
                                    │
                                    ▼
                  +-----------------------------------+
                  |  Analizador Fourier (Autotuning)  |
                  +-----------------------------------+
                                    │
                   ┌────────────────┴─────────────────┐
                   │ baud = 1200                      │ baud ≤ 600
                   ▼                                  ▼
        +--------------------+             +--------------------+
        |  Filtros Pasa-Banda|             |  Filtros Pasa-Banda|
        |  Butterworth       |             |  Butterworth       |
        |  (filtfilt,        |             |  (lfilter,         |
        |   ZERO-PHASE)      |             |   causal)          |
        +--------------------+             +--------------------+
                   │                                  │
                   ▼                                  ▼
        +--------------------+             +--------------------+
        | Envolventes +      |             | Envolventes +      |
        | LP Zero-Phase      |             | LP Causal          |
        +--------------------+             +--------------------+
                   │                                  │
                   ▼                                  │
        +--------------------+                       │
        | Normalización      |                       │
        | Geométrica Absoluta|                       │
        | (centro p5-p95)    |                       │
        +--------------------+                       │
                   │                                  │
                   ▼                                  │
        +--------------------+                       │
        | Squelch de Inicio  |                       │
        | (primer pulso >0.5)|                       │
        +--------------------+                       │
                   └────────────────┬─────────────────┘
                                    │
                                    ▼
                  +-----------------------------------+
                  | Búsqueda de Fase (Grid Search)    |
                  | + DPLL (Kp/Ki desde config.py)    |
                  +-----------------------------------+
                                    │
                                    ▼
                  +-----------------------------------+
                  |    Cálculo de BER y Confianza     |
                  +-----------------------------------+
```

1.  **Acondicionamiento (Filtro FIR Kaiser):** Un filtro de respuesta al impulso finita (FIR) de fase lineal de orden 127 aísla la banda útil (300 Hz a 3000 Hz), eliminando ruidos fuera de banda tales como zumbidos de red de 50/60 Hz.
2.  **Autocalibración Espectral (Transformada Rápida de Fourier):** Ejecuta una transformada rápida de Fourier para detectar las frecuencias reales del transmisor (Mark y Space), compensando corrimientos locales debidos a derivas térmicas de los osciladores.
3.  **Filtros de Banda Adaptativos (bifurcado):**
    - **1200 bd:** Usa `signal.filtfilt()` (fase nula, retardo de grupo cero) tanto en los filtros pasa-banda como en el filtro pasa-bajos de envolvente. Esto elimina el retardo de grupo de ~8.8 muestras que causaba ISI sistemático a 1200 bd con el método causal.
    - **≤ 600 bd:** Usa `signal.lfilter()` causal clásico, que funciona correctamente a estas velocidades donde el retardo de grupo es despreciable en proporción al período de símbolo.
4.  **Detección y Balance de Envolvente:** Estima las envolventes de amplitud y aplica un factor de ganancia $g$ para compensar la atenuación diferencial de frecuencia: $y_{\text{cruda}} = env_{\text{mark}} - g \cdot env_{\text{space}}$. Para 1200 bd, se aplica adicionalmente:
    - **Normalización Geométrica Absoluta:** La señal se normaliza al rango $[-1, +1]$ usando el punto medio exacto entre el percentil 5 y 95 del burst ($y = (y_{\text{cruda}} - c) / a$, con $c$ el centro y $a$ la semiplitud), robusta frente a tramas asimétricas.
    - **Squelch de Inicio:** Se detecta el primer pulso real ($|y| > 0.5$) y se reposiciona `bloque_inicio` exactamente un símbolo antes de él, evitando el falso enganche del reloj (*false lock*) sobre el silencio inicial.
5.  **Búsqueda de Fase y Sintonización DPLL:** Realiza una búsqueda en rejilla (*Grid Search*) de la fase temporal inicial. Para 1200 bd, la ventana de búsqueda se amplía a $15 \times N_s$ muestras para compensar el retardo residual de la cadena de filtros. A continuación, el DPLL se sintoniza también por grilla sobre los candidatos de $K_p$ y $K_i$ definidos en `config.DPLL_KP_CANDIDATOS` y `config.DPLL_KI_CANDIDATOS`. El período de símbolo $N_s = f_s / \text{baud}$ se calcula siempre dinámicamente, sin valores hardcodeados por velocidad.
6.  **Evaluación de BER:** Alinea la secuencia demodulada mediante correlación cruzada contra el patrón local PRBS-7 de 127 bits de Golomb ($y(n) = y(n-6) \oplus y(n-7)$) y calcula la Tasa de Error de Bit (BER) sobre la ráfaga completa.

---

## 🛠️ Instalación de Dependencias

Se requiere tener instalado **Python 3.10+** en el sistema. Para instalar los requisitos matemáticos necesarios, ejecuta:

```bash
pip install -r requirements.txt
```

---

## ⚡ Ejecución del Pipeline Completo

El pipeline de procesamiento se divide en **tres etapas auditables e independientes**:

1. **Segmentar** los audios continuos en ráfagas individuales → `generate_bursts.py`
2. **Demodular** cada ráfaga y medir el BER → `run_suite.py`
3. **Consolidar** los resultados en un CSV clasificado por distancia y baudrate → `generate_csv.py`

Para ver la guía detallada de los pasos 1 y 2, consulte:
*   [Guía del Flujo de Trabajo Integrado con Ráfagas (workflow_bursts.md)](./workflow_bursts.md)
*   [Documentación Técnica del Segmentador (README_generate_bursts.md)](./README_generate_bursts.md)

### 1. Segmentar Ráfagas
Para segmentar automáticamente un directorio de audios continuos y guardarlos en una carpeta de salida:
```bash
python3 processing/generate_bursts.py data/<dataset>/ -o data_generated/<dataset>/ --grid
```

### 2. Demodular con run_suite.py
Para ejecutar la suite sobre el directorio de ráfagas generadas, ejecute desde el directorio raíz del repositorio y **guarde la salida en un archivo de texto** para el paso siguiente:
```bash
python3 processing/run_suite.py data_generated/<dataset>/ > salida.txt
```

### Gráficos de Salida (en carpeta `reportes/`):
*   `perfil_error_temporal_[alias].png`: Muestra de forma espacial la ubicación exacta de los bits recibidos correctamente (en verde) y los bits erróneos (en rojo) a lo largo de los miles de bits de la ráfaga, permitiendo diagnosticar la dinámica del transitorio de enganche y del canal.

---

## 📊 Generación del CSV de Resultados (`generate_csv.py`)

El script `generate_csv.py` toma la salida de texto de `run_suite.py` y los archivos de telemetría GPS de los bursts para generar un CSV con el BER clasificado por **distancia real** (calculada por GPS) y **baudrate**.

### Lógica de distancias

El script determina la distancia de cada sesión de medición de forma automática:
1. Lee las coordenadas GPS (lat/lon WGS-84) de los archivos `_burst_*.csv` del directorio
2. Ordena cronológicamente por timestamp GPS → el primer burst es el **punto de referencia (0 m)**
3. Calcula la distancia haversine de cada burst respecto al punto de referencia
4. Agrupa los bursts en sesiones usando un salto de distancia como separador (configurable o automático)

### Cálculo de BER

Las ráfagas del mismo baudrate dentro de una sesión se **acumulan** (no promedian), ya que la división en bursts existe únicamente por protección térmica del transmisor:

```
BER (%) = ( Σ errores de todas las ráfagas de la sesión/baudrate )
          ──────────────────────────────────────────────────────── × 100
          ( Σ bits   de todas las ráfagas de la sesión/baudrate )
```

### Uso

```bash
# Forma básica (umbral de sesión automático)
python3 processing/generate_csv.py -i salida.txt -d data_generated/<dataset>/ -o resultado.csv

# Con umbral de sesión explícito (en metros)
python3 processing/generate_csv.py -i salida.txt -d data_generated/<dataset>/ -o resultado.csv -t 200
```

| Argumento | Descripción | Requerido |
|---|---|---|
| `-i` / `--input` | Archivo de texto con la salida de `run_suite.py` | ✅ |
| `-d` / `--dir` | Directorio con los `_burst_*.csv` de GPS | ✅ |
| `-o` / `--output` | Archivo CSV de salida | ✅ |
| `-t` / `--threshold` | Umbral en metros para detectar cambio de sesión | Opcional |

> Si `-t` se omite, el umbral se calcula automáticamente como `media + 2σ` de los saltos de distancia consecutivos.

### Formato del CSV de salida

```
Distancia_m,10,50,150,300,600,1200
0,0.00,0.00,0.36,0.03,0.06,5.39
552,0.00,0.08,0.05,0.04,0.06,5.80
...
```

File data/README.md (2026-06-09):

# 💾 *Dataset* Experimental y Telemetría GPS

Esta carpeta contiene los archivos de metadatos de posicionamiento y telemetría de las campañas de ensayo en campo y laboratorio de la plataforma **ORR**.

> [!IMPORTANT]
> **Acceso a los Archivos de Audio WAV:**
> Debido al tamaño de los archivos de audio crudo digitalizado (cientos de megabytes en total, superando los límites sugeridos de almacenamiento en Git/GitHub), las grabaciones de audio `.wav` se alojan externamente en la siguiente carpeta compartida:
> 
> *   **Enlace de Descarga del *Dataset* Completo (Google Drive):** [Bases de Datos de Audio ORR](https://drive.google.com/drive/folders/1wKw8cH1Ox6S6E19gmR8-GltFr6CDUwmw?usp=sharing)
> 
> Cada archivo `.csv` aquí presente está indexado por fecha y hora y se corresponde biunívocamente con el archivo de audio `.wav` de idéntico nombre alojado en el Drive.

---

## 📂 Distribución de la Base de Datos

La base de datos en Google Drive y los metadatos en el repositorio están organizados en dos grandes conjuntos según el entorno y la metodología de ensayo:

1. **`campo/` (Ensayos de Campo):**
   * Contiene las mediciones experimentales obtenidas bajo follaje real en un olivar de producción intensiva en la provincia de San Juan, Argentina.
   * Se operó con una potencia de $1.0\text{ W}$ (Low Power del transceptor Baofeng UV-82) en la frecuencia de UHF de $433\text{ MHz}$ con polarización horizontal.
   * Las mediciones cubren distancias de hasta 1500 metros bajo condiciones severas de obstrucción por biomasa húmeda y copas de árboles adultos.

2. **`libre/` (Ensayos en Línea de Vista / Campo Libre):**
   * Contiene los registros correspondientes a mediciones de calibración en espacio libre (laboratorio y campo abierto con línea de vista directa).
   * Se encuentra subdividido en carpetas según la distancia física (en metros) entre el transmisor y el receptor:
     * `5/`: Calibración y pruebas a corta distancia (5 metros).
     * `500/`: Pruebas a media distancia en línea de vista (500 metros).
     * `1000/`: Pruebas a larga distancia con obstrucción mínima (1000 metros).
     * `1500/`: Pruebas de límite de enlace en campo libre (1500 metros).

---

## 🏷️ Significado de los Nombres de Archivos

Los archivos siguen una nomenclatura estandarizada que garantiza la trazabilidad temporal y espacial:

`audio_sdr_YYYYMMDD_HHMMSS.[wav|csv]`

Donde:
* **`audio_sdr`**: Prefijo identificador del sistema de adquisición digitalizado.
* **`YYYYMMDD`**: Fecha de la captura (Año, Mes, Día) reportada por el dispositivo del operador.
* **`HHMMSS`**: Hora de la captura (Hora, Minuto, Segundo) en tiempo local del operador.

### Correspondencia Biunívoca (1-a-1)
* El archivo `.wav` (audio crudo) y el archivo `.csv` (metadatos) que poseen el mismo timestamp se corresponden exactamente a la misma medición física.
* **Archivos con sufijo `_burst_X.wav`** (ej. `audio_sdr_20260604_180700_burst_1.wav`): Son segmentos de audio extraídos de la grabación continua correspondientes a ráfagas individuales de transmisión útiles, recortados y procesados de manera *offline* mediante la suite de demodulación.

---

## ⚙️ Metodología de Grabación (Receptor RX / Web-DAQ)

Las grabaciones de audio analógico del receptor de radio FM se digitalizan empleando un microcontrolador **Raspberry Pi Pico 2W** configurado como un adquisidor de datos inalámbrico (Web-DAQ). El flujo de grabación opera de la siguiente manera:

1. **Adquisición Analógica de Alta Precisión (Core 1):**
   * El microcontrolador ejecuta MicroPython sobre el chip RP2350 overclockeado a $150\text{ MHz}$ para inmunizar los lazos de tiempo críticos.
   * En el **Core 1**, un timer por hardware lee la entrada analógica `GP26` (ADC0) a una tasa fija y estable de **$19200\text{ Hz}$** ($f_s$).
   * Para anular la latencia y las derivas de tiempo inducidas por el recolector de basura (*garbage collector*), se preasigna un esquema de doble búfer (*ping-pong*) de un segundo de duración ($19200$ muestras) y se deshabilita temporalmente el *Garbage Collector* en caliente con `gc.disable()`.
   * El offset analógico unipolar de $1.65\text{ V}$ de la placa se remueve restando $32768$ a la lectura directa de 16 bits sin signo del ADC, produciendo muestras de **16-bit PCM Signed** (con valores en el rango $[-32768, +32767]$).

2. **Transmisión de Datos por Wi-Fi (Core 0):**
   * El **Core 0** levanta un Punto de Acceso Wi-Fi local de nombre `PicoSDR` (IP `192.168.4.1`, puerto 80).
   * El operador se conecta con su teléfono celular y accede al panel web (HTML/JS) servido en bloques pequeños (*chunked*) por el microcontrolador.
   * Al conectar, el navegador inicia una conexión persistente al *endpoint* de streaming TCP `/stream`. El Core 0 de la Pico 2W transmite los buffers PCM de Core 1 a través del socket de forma inalámbrica.

3. **Almacenamiento y Telemetría en el Cliente (Navegador Móvil):**
   * **Visualización en Tiempo Real:** El script JavaScript en el navegador calcula la transformada rápida de Fourier para el VU-meter, evaluando la densidad espectral en la frecuencia del tono de Mark ($1200\text{ Hz}$) para filtrar la estática del silenciador de la radio.
   * **Registro GPS Activo:** El celular obtiene de forma continua la posición GPS por hardware en modo de alta precisión.
   * **Descarga Simultánea:** Al pulsar "Detener y Guardar", el script de JavaScript en el navegador empaqueta las muestras PCM acumuladas en la memoria RAM, inyecta una **cabecera estándar RIFF/WAVE de 44 bytes** y genera la descarga automática y simultánea del archivo de audio `.wav` y del archivo de telemetría `.csv` con la información del GPS y del canal.

---

## 📡 Estructura y Parámetros de la Secuencia Transmitida (TX)

Para caracterizar el canal y analizar la tasa de error de bit (BER), el transmisor (TX) genera secuencias balanceadas deterministas de datos digitales.

### Generación de la Secuencia PRBS-7
El firmware del transmisor implementa un Registro de Desplazamiento con Retroalimentación Lineal (**LFSR** — *Linear Feedback Shift Register*) con arquitectura Fibonacci:
* **Polinomio generador:** $x^7 + x^6 + 1$ (Polinomio característico de Golomb, 1982).
* **Recurrencia:** $y(n) = y(n-6) \oplus y(n-7)$.
* **Semilla inicial (*Seed*):** `0x7F` (todos los bits en $1$). El estado `0x00` está estrictamente prohibido por ser un punto fijo muerto.
* **Longitud maximal:** $2^7 - 1 = 127$ bits.
* **Propiedades estadísticas:** Contiene exactamente 64 unos y 63 ceros. Incluye rachas de hasta 7 bits idénticos consecutivos para estresar el recuperador de fase y de reloj del receptor.

### Modulación y Frecuencias AFSK
La secuencia binaria es modulada en audio analógico mediante **AFSK** (*Audio Frequency Shift Keying*) con fase continua (CPFSK) sintetizada en la Pico 2W mediante DDS (Direct Digital Synthesis) mapeado a PWM de hardware a $125\text{ kHz}$:
* **Mark (Bit Lógico 1):** Tono senoidal de **$1200\text{ Hz}$**.
* **Space (Bit Lógico 0):** Tono senoidal de **$2400\text{ Hz}$**.
* **Velocidades de prueba (Baudrates):** El sistema rota cíclicamente entre 10, 50, 150, 300, 600 y 1200 baudios.

### Protección Térmica y Fragmentación de Ensayos
Para que los resultados sean estadísticamente robustos, cada punto de medición requiere recibir un volumen total de **$12700\text{ bits}$** ($100$ ciclos PRBS-7 completos). Sin embargo, el paso final de potencia RF del transceptor portátil Baofeng UV-82 no está diseñado para transmisión digital continua de largo aliento. 

Para evitar daños térmicos y sobrecalentamiento, se limita la transmisión continua por ráfaga a un máximo de **30 segundos**. Por ello, el volumen de bits de ensayo se fragmenta en ráfagas (*bursts*) con pausas obligatorias de enfriamiento (Duty Cycle $\le 50\%$):

| Velocidad (bd) | Bits por Ráfaga | Cantidad de Ráfagas | Duración Activa TX | Pausa de Enfriamiento (s) | Comentarios |
| :---: | :---: | :---: | :---: | :---: | :--- |
| **10 bd** | 127 | 1 | ~12.7 s | 30 s | Modificado para evitar excesiva duración térmica a velocidad lenta. |
| **50 bd** | 1270 | 2 | ~25.4 s | 27 s | Fragmentado en 2 ráfagas de 10 ciclos PRBS-7 cada una. |
| **150 bd** | 3175 | 2 | ~21.1 s | 23 s | Fragmentado en 2 ráfagas de 25 ciclos PRBS-7 cada una. |
| **300 bd** | 6350 | 2 | ~21.1 s | 23 s | Fragmentado en 2 ráfagas de 50 ciclos PRBS-7 cada una. |
| **600 bd** | 12700 | 1 | ~21.1 s | 23 s | Ráfaga única de 100 ciclos PRBS-7. |
| **1200 bd** | 12700 | 1 | ~10.6 s | 12 s | Ráfaga única de 100 ciclos PRBS-7. |

*Nota:* Los tiempos de transmisión activa reales del PTT incluyen 1.0s de pre-delay (para la apertura de squelch en RX) y 1.0s de post-delay (para asegurar la salida física del búfer de audio antes de soltar el PTT).

---

## 📊 Formato de Datos de Telemetría (CSV)

Cada archivo `.csv` descargado de forma inalámbrica posee la siguiente estructura de metadatos:

| Parámetro | Ejemplo | Descripción |
| :--- | :--- | :--- |
| **Archivo_Audio** | `audio_sdr_20260606_135923.wav` | Nombre del audio WAV capturado asociado a la medición. |
| **Timestamp_Celular_Local** | `2026-06-06T13:59:23-03:00` | Marca temporal local reportada por el dispositivo del operador. |
| **Latitud** | `-31.5423918` | Latitud en grados decimales bajo sistema geodésico WGS-84. |
| **Longitud** | `-68.6092303` | Longitud en grados decimales bajo sistema geodésico WGS-84. |
| **Precision_Metros** | `3.00` | Margen de error horizontal reportado por el chip GPS del celular. |
| **Altitud_Metros** | `719.30` | Altitud elipsoidal en metros sobre el nivel del mar. |
| **Velocidad_M_S** | `0.07` | Velocidad de traslación del celular del operador (m/s). |
| **Rumbo_Grados** | `No disponible` | Dirección de movimiento en grados sexagesimales (si aplica). |
| **Timestamp_GPS_UTC** | `2026-06-06T16:59:22.645Z` | Momento exacto de captura geolocalizada reportada por satélite (UTC). |
| **Dispositivo** | `Navegador Web Movil` | Interfaz física cliente que controló la captura. |
| **Frecuencia_Muestreo_Hz**| `19200` | Tasa de digitalización nominal del ADC de la Pico 2W (Hz). |
| **Muestras_Totales** | `806400` | Cantidad total de muestras de 16 bits en el *buffer* final. |
| **Duracion_Segundos** | `42.000` | Duración temporal exacta calculada en segundos. |
| **Proyecto** | `Intercomunicador SDR - INAUT (UNSJ)` | Contexto de investigación del ensayo. |

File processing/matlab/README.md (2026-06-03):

# 🧮 Referencia de Procesamiento en MATLAB

Este directorio contiene el script histórico de referencia desarrollado en MATLAB para simular y validar el algoritmo de demodulación Goertzel antes de su portabilidad a Python y MicroPython.

---

## 📂 Contenido

*   **`goertzel_go.m`**: Script principal de MATLAB que carga una señal grabada en formato `.wav`, aplica el preprocesamiento y ejecuta recursivamente las ecuaciones del filtro de respuesta al impulso infinita de Goertzel para calcular las envolventes espectrales de Mark y Space.

---

## ⚙️ Notas de Uso

*   **Entrada de Datos**: El script espera cargar archivos de audio `.wav` digitalizados a la frecuencia de muestreo unificada de la radio.
*   **Parámetros de Simulación**:
    *   Frecuencias nominales de tonos: $f_1 = 1200\text{ Hz}$ y $f_0 = 2400\text{ Hz}$.
    *   Tasa de muestreo nominal: $f_s = 19200\text{ Hz}$ (o $8000\text{ Hz}$ en las primeras campañas de ensayo analizadas en la subcarpeta `matlab` de desarrollo).
*   **Valor Científico**: Este script sirvió para contrastar la exactitud del cálculo de energía cuadrática de Goertzel frente a la transformada rápida de Fourier discreta, demostrando una reducción del costo computacional en el procesador, lo que habilitará su integración en tiempo real a bordo de la Raspberry Pi Pico.

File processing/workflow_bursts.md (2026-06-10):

# 🔄 Flujo de Trabajo de Procesamiento con Segmentación Automática (`workflow_bursts.md`)

Este documento detalla el flujo de trabajo integrado para la ingesta, segmentación y demodulación de señales en el proyecto **Outdoor Radio Robotics (ORR)**. Este flujo reemplaza el filtrado manual de archivos mediante el uso del segmentador inteligente de ráfagas (`generate_bursts.py`).

---

## 📌 Contexto y Problemática

El receptor de telemetría en campo graba de forma continua toda la sesión de transmisión. Esto genera archivos `.wav` de larga duración que contienen:
1. Ruido blanco de FM inicial.
2. Tonos de preámbulo/cuenta regresiva del transmisor.
3. **Múltiples ráfagas activas (bursts)** de datos modulados en AFSK separados por silencios de enfriamiento (cooldown) de la radio.
4. Ruido de estática de FM al abrirse el squelch y clics de desconexión (PTT).

Dado que la suite de demodulación (`run_suite.py`) procesa el primer bloque activo sostenido que detecta, pasarle directamente el archivo continuo resulta en la pérdida de las ráfagas secundarias y en métricas distorsionadas. El nuevo flujo automatiza de manera robusta la extracción de estas ráfagas individuales.

---

## 🗺️ Mapa del Flujo de Trabajo Integrado

El flujo de procesamiento digital completo se compone de las siguientes etapas:

```
  [ Grabaciones Continuas ] + [ Telemetría GPS (.csv) ]  <-- Captura en Campo (Web-DAQ)
             │
             ▼
 ┌──────────────────────────────────────────────────────┐
 │ 1. Segmentación Inteligente (generate_bursts.py)    │
 │    • Filtro pasabanda Butterworth (1-2.6 kHz)        │
 │    • Detección automática de baudrate                │
 │    • Optimización de umbral RMS (Búsqueda en Grilla) │
 │    • Validación espectral por SNR de tonos AFSK      │
 └──────────────────────────────────────────────────────┘
             │
             ▼
  [ Ráfagas Segmentadas WAV ] + [ Mapeo de CSVs de GPS ]
             │
             ▼
 ┌──────────────────────────────────────────────────────┐
 │ 2. Demodulación y Análisis (run_suite.py)            │
 │    • Filtro FIR Kaiser (300-3000 Hz)                 │
 │    • Detección y balance dinámico de envolventes      │
 │    • Búsqueda en grilla de fase temporal (DPLL)      │
 │    • Decisión de bit y correlación PRBS-7            │
 └──────────────────────────────────────────────────────┘
             │
             ▼
    [ Salida de texto: BER (%) / Confianza Ck por archivo ]
             │
             ▼
 ┌──────────────────────────────────────────────────────┐
 │ 3. Consolidación de Resultados (generate_csv.py)    │
 │    • Lectura de GPS desde _burst_*.csv               │
 │    • Agrupamiento por sesión (distancia haversine)   │
 │    • BER acumulado por sesión × baudrate              │
 └──────────────────────────────────────────────────────┘
             │
             ▼
    [ CSV: Distancia_m × Baudrate → BER (%) ]
```

---

## ⚡ Guía de Ejecución Paso a Paso

### Paso 1: Organización del Dataset de Entrada
Ubique los archivos continuos originales grabados del receptor en la estructura estándar de directorios.
Ejemplo:
```
data/libre/
├── 5/
│   ├── audio_sdr_20260604_172254.wav
│   └── audio_sdr_20260604_172254.csv (Telemetría original)
├── 500/
...
```

### Paso 2: Generación Automática de Ráfagas (`generate_bursts.py`)
Ejecute el segmentador automático sobre la carpeta de datos crudos. Se recomienda utilizar el flag `--grid` para que el script determine automáticamente la velocidad de transmisión, busque la cantidad esperada de ráfagas y optimice dinámicamente el umbral RMS de corte por archivo.

```bash
python3 ORR/processing/generate_bursts.py data/libre/5 -o data_generated/5 --grid
```

*Este comando escaneará `data/libre/5`, excluirá archivos que ya posean la nomenclatura de ráfaga y generará los archivos limpios segmentados (`audio_sdr_*_burst_X.wav`) en la carpeta `data_generated/5`.*

### Paso 3: Vinculación de Metadatos GPS de Telemetría (Automática)
Para conservar la trazabilidad de la posición GPS del ensayo y georreferenciar cada ráfaga individual, el segmentador (`generate_bursts.py`) detecta automáticamente si existe un archivo `.csv` de telemetría asociado a la grabación `.wav` principal. 

Si está presente, **copiará y renombrará de forma automática** el archivo de telemetría original (por ejemplo, generando `audio_sdr_..._burst_X.csv` al lado de `audio_sdr_..._burst_X.wav`). **No es necesario ejecutar scripts de terminal adicionales para esta tarea.**

### Paso 4: Ejecución del Demodulador y Medición de BER
Una vez generadas las ráfagas individuales en el directorio destino, invoque la suite de demodulación directamente sobre dicha carpeta:

```bash
python3 ORR/processing/run_suite.py data_generated/5
```

La suite detectará las ráfagas y procesará la secuencia completa de bits transmitidos según la velocidad de cada archivo para generar los reportes de BER y los gráficos de error temporal en la carpeta `reportes/`.

### Paso 5: Generación del CSV de Resultados

Una vez obtenida la salida de `run_suite.py` en `salida.txt`, ejecute `generate_csv.py` para clasificar los resultados por distancia GPS y baudrate:

```bash
python3 ORR/processing/generate_csv.py -i salida.txt -d data_generated/<dataset>/ -o resultado.csv
```

El script leerá las coordenadas GPS de los `_burst_*.csv`, agrupará automáticamente las ráfagas en sesiones por distancia y producirá el CSV de resultados. Puede especificarse un umbral manual de sesión con `-t <metros>` si la detección automática no es adecuada para el dataset.

---

## 🎛️ Parámetros de Ingesta Clave en el Segmentador

El script `generate_bursts.py` expone parámetros configurables por línea de comandos para adaptarse a diferentes niveles de ruido de canal sin necesidad de editar el código fuente:

*   `--grid`: **(Recomendado)** Activa la grilla de búsqueda RMS automática. Evalúa umbrales de energía de ráfaga y elige el que reporte la cantidad esperada de ráfagas con la mayor SNR promedio.
*   `--snr-threshold` (Por defecto `10.0` dB): Umbral de validación espectral. Filtra ruidos de estática y clicks de squelch de banda ancha asegurando que el segmento contenga energía concentrada en los tonos Mark ($1200\text{ Hz}$) y Space ($2400\text{ Hz}$).
*   `--padding` (Por defecto `1.0` s): Tiempo de seguridad en segundos agregado antes y después del segmento activo para garantizar que no se trunque el preámbulo de sincronización ni el cierre de la trama.

---

## 📈 Verificación y Aseguramiento de Calidad (QA)

Al procesar un nuevo dataset o integrar el segmentador en el pipeline:
1. **Validación Visual:** Inspeccione los gráficos generados en `reportes/` para corroborar que el enganche de fase (DPLL) y el balance de envolventes se realicen correctamente desde el inicio de la ráfaga.
2. **Consistencia de BER:** Verifique que las sesiones detectadas por `generate_csv.py` coincidan con las distancias nominales del ensayo. Si el número de sesiones detectadas no es el esperado, ajuste el umbral con `-t`.

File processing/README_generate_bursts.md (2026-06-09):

# ✂️ Segmentador Automático de Ráfagas AFSK (`generate_bursts.py`)

Este documento detalla el funcionamiento, arquitectura y flujo de trabajo del script `generate_bursts.py` para la extracción y segmentación automática de ráfagas activas de modulación a partir de grabaciones continuas de audio de telemetría.

---

## 💡 Razón de Ser y Problemática

El transceptor analógico FM (Baofeng UV-82) opera con una máquina de estados de transmisión que fragmenta los datos en ráfagas (bursts) separadas por silencios de enfriamiento (cooldown) para evitar daños térmicos. El receptor graba de forma continua todo el ensayo, generando un único archivo de audio WAV de larga duración que contiene:
1. Ruido de fondo inicial y transitorios de conexión (PTT click).
2. Tono de preámbulo / pre-aviso.
3. Ráfagas de datos reales (AFSK 1200/2400 Hz).
4. Silencios intermedios con **ruido de estática de FM** de gran amplitud si el squelch se abre.
5. Clics de desconexión finales.

La suite de demodulación (`run_suite.py`) está diseñada para analizar el primer bloque activo sostenido. Si procesamos el archivo continuo completo, no podremos evaluar las ráfagas subsiguientes y duplicaremos el análisis de la primera. El script `generate_bursts.py` automatiza la extracción limpia de estas ráfagas de forma inteligente.

---

## 🛠️ Arquitectura y Flujo de Detección

El script procesa cada grabación continua a través de 5 etapas secuenciales de procesamiento digital de señales:

```
    +-------------------------------------------------------------+
    |                Archivo WAV de Entrada Continuo              |
    +-------------------------------------------------------------+
                                   │
                                   ▼
    +-------------------------------------------------------------+
    |       1. Filtro Pasabanda Butterworth (1000 - 2600 Hz)      |
    +-------------------------------------------------------------+
                                   │
                                   ▼
    +-------------------------------------------------------------+
    |       2. Detector de Velocidad de Transmisión (Baudrate)    |
    |      (Calibra tonos y consulta el número de bursts esperado)|
    +-------------------------------------------------------------+
                                   │
                                   ▼
    +-------------------------------------------------------------+
    |          3. Grilla de Búsqueda de Umbral RMS (Grid)         |
    |    (Busca umbrales candidatos de energía entre 0.05 y 0.50) |
    +-------------------------------------------------------------+
                                   │
                                   ▼
    +-------------------------------------------------------------+
    |        4. Validación Espectral AFSK (SNR de Tonos)          |
    |   (Compara la energía a 1200/2400 Hz vs el promedio de ruido)|
    |   Rechaza clics y estática de FM de banda ancha (SNR < 10dB) |
    +-------------------------------------------------------------+
                                   │
                                   ▼
    +-------------------------------------------------------------+
    |             5. Extracción con Padding y Exportación         |
    |        (Aplica 1.0s de margen para preservar preámbulo)     |
    +-------------------------------------------------------------+
```

---

## ⚡ Flujo de Trabajo Integrado

El procesamiento del dataset experimental se simplifica a un flujo de dos comandos:

### Paso 1: Generación de ráfagas
Ejecute el segmentador sobre la carpeta original de grabaciones continuas para generar los archivos de ráfaga limpios en una carpeta temporal:
```bash
python3 ORR/processing/generate_bursts.py data/libre/5 -o data_generated/5 --grid
```

### Paso 2: Demodulación y cálculo de BER
Corra la suite de demodulación directamente sobre la carpeta con las ráfagas generadas:
```bash
python3 ORR/processing/run_suite.py data_generated/5
```

---

## 🎛️ Parámetros de Configuración (CLI)

El script es 100% configurable por consola para evitar la necesidad de alterar el código en el futuro:

| Parámetro | Comando | Valor Defecto | Descripción |
| :--- | :--- | :---: | :--- |
| **Entrada** | *Posicional* | *(Obligatorio)* | Ruta al archivo `.wav` continuo o al directorio que contiene los archivos WAV principales. |
| **Directorio Destino** | `-o` / `--output-dir` | *Mismo origen* | Directorio donde se guardarán las ráfagas extraídas `<basename>_burst_X.wav`. |
| **Margen de Seguridad** | `-p` / `--padding` | `1.0` | Padding de audio en segundos que se añadirá antes y después de cada ráfaga. |
| **Umbral RMS Defecto** | `-t` / `--threshold` | `0.20` | Fracción del RMS de referencia para la detección si no se usa la grilla. |
| **Umbral SNR AFSK** | `--snr-threshold` | `10.0` | Relación de energía lineal mínima del tono Mark/Space vs. ruido de fondo. |
| **Duración Mínima** | `--min-duration` | `4.0` | Duración mínima en segundos que debe durar el bloque activo. |
| **Grilla Automática** | `--grid` | *Desactivado* | Activa la grilla de búsqueda para optimizar el umbral RMS dinámicamente por archivo. |
| **Modo Silencioso** | `-q` / `--quiet` | *Desactivado* | Deshabilita la impresión detallada de la segmentación en consola. |

### Ejemplo de Configuración Avanzada:
Si se trabaja con un canal extremadamente ruidoso, se puede aumentar el umbral SNR y reducir el padding para evitar incluir clicks de squelch adyacentes:
```bash
python3 ORR/processing/generate_bursts.py data/libre/1500 -o data_generated/1500 --grid --snr-threshold 15.0 --padding 0.5
```

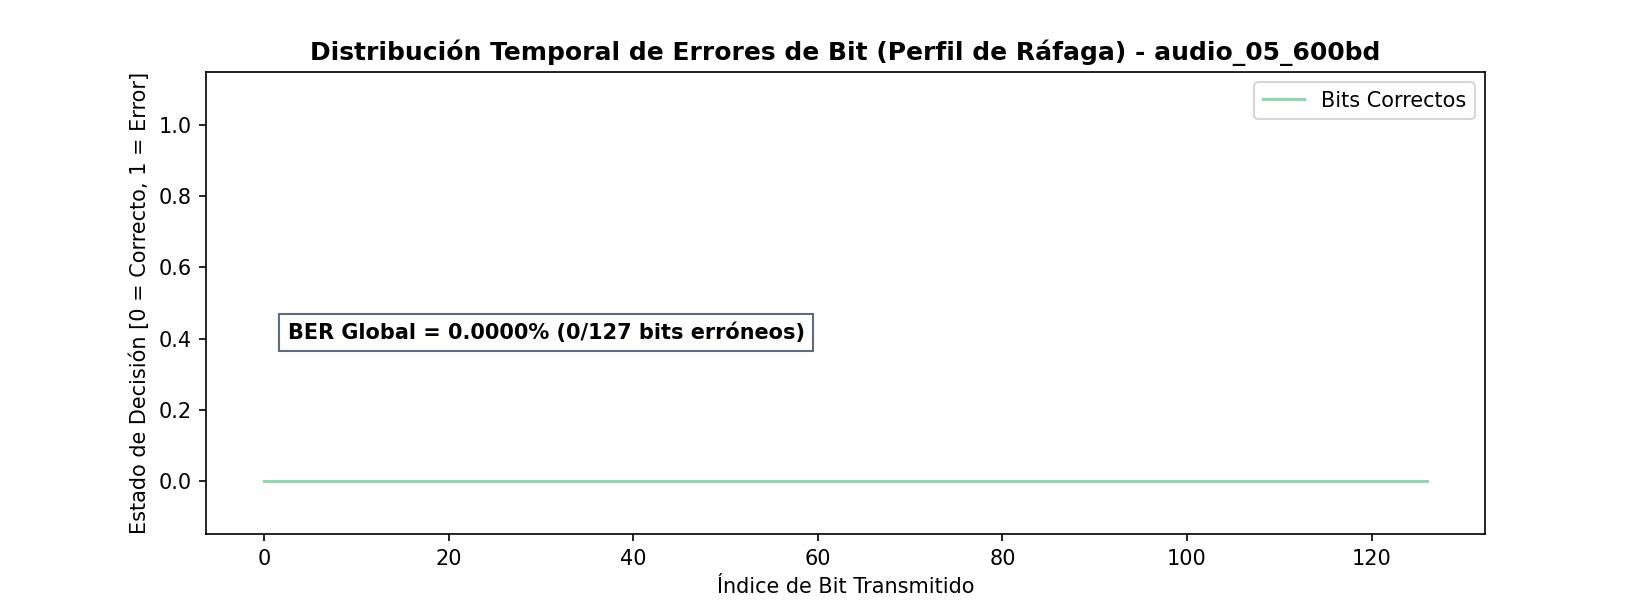
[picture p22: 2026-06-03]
processing/reportes/perfil_error_temporal_audio_05_600bd.png

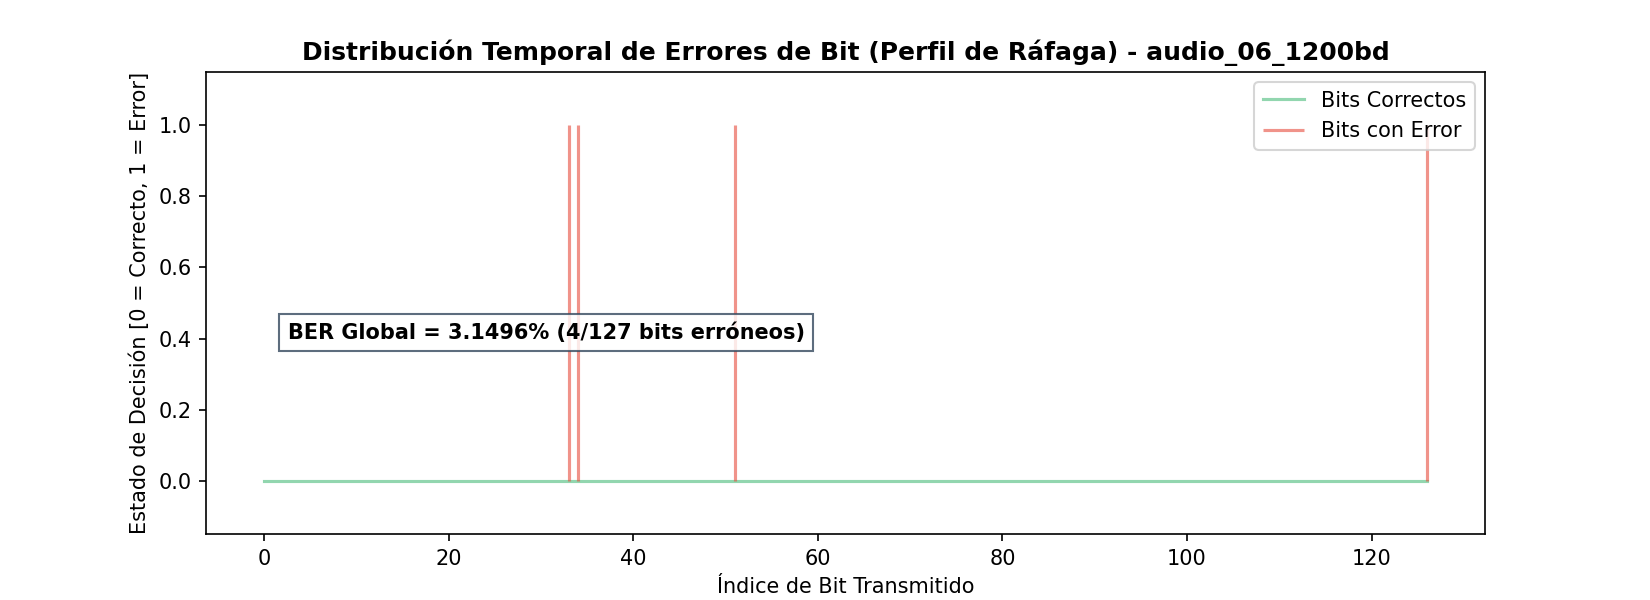
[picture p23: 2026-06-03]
processing/reportes/perfil_error_temporal_audio_06_1200bd.png

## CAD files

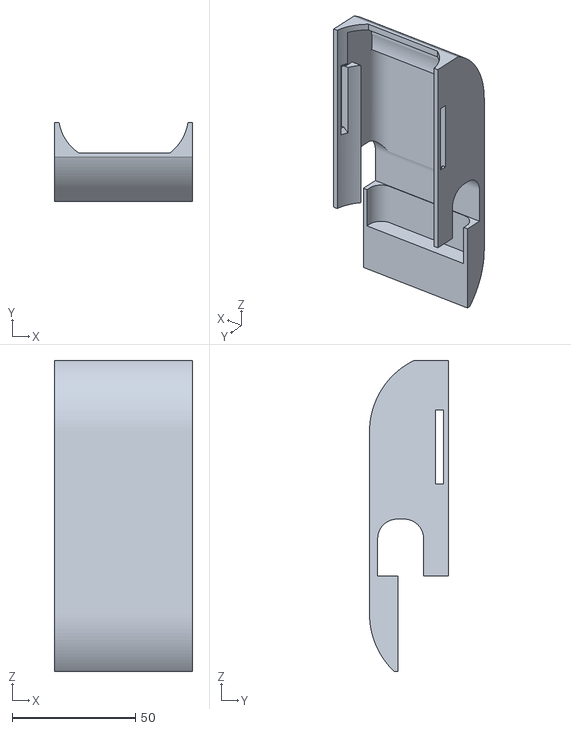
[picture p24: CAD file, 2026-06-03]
mechanics/base_v4-carcasa.stl
56.0 x 32.0 x 126.0

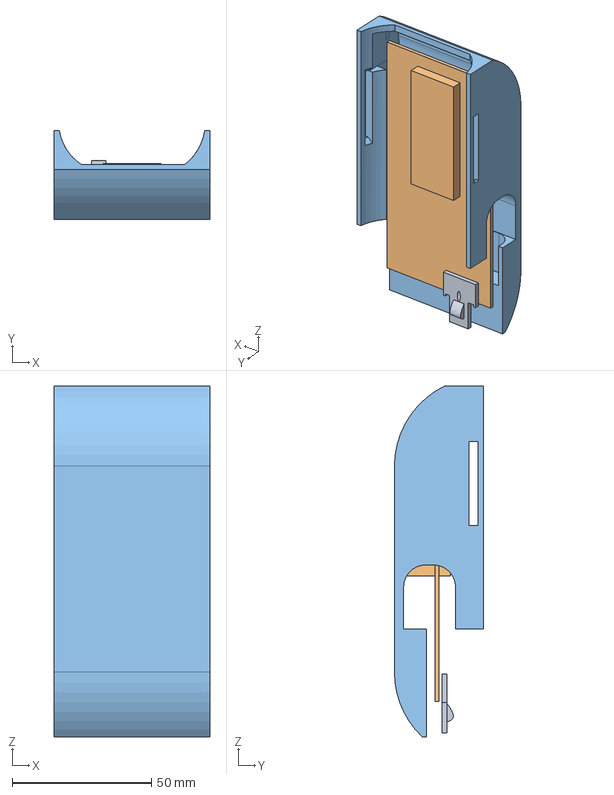
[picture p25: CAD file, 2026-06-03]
mechanics/base_v4.FCStd
56.0 x 32.0 x 126.0 mm
lengueta
placa_base
carcasa

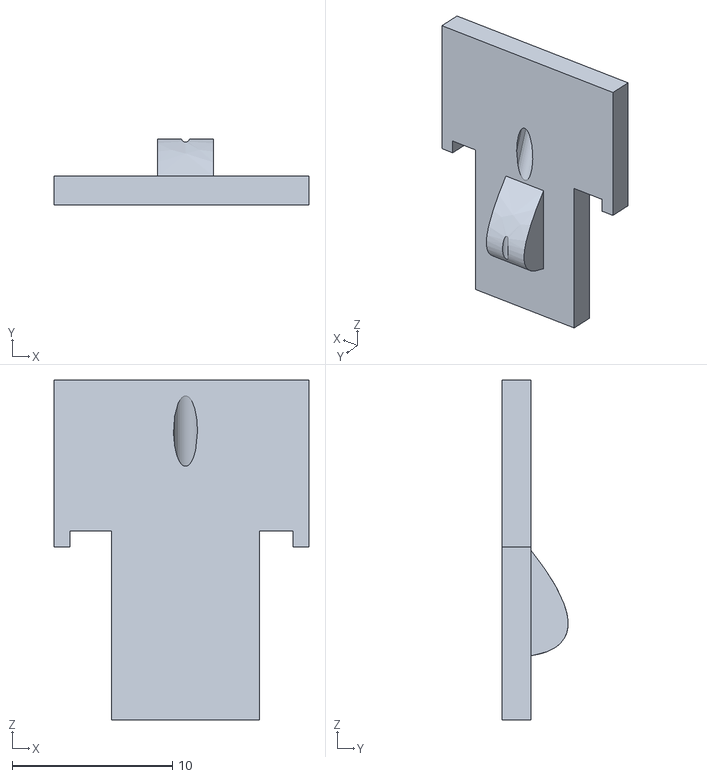
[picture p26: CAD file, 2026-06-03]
mechanics/lengueta.stl
15.9 x 4.13 x 21.2

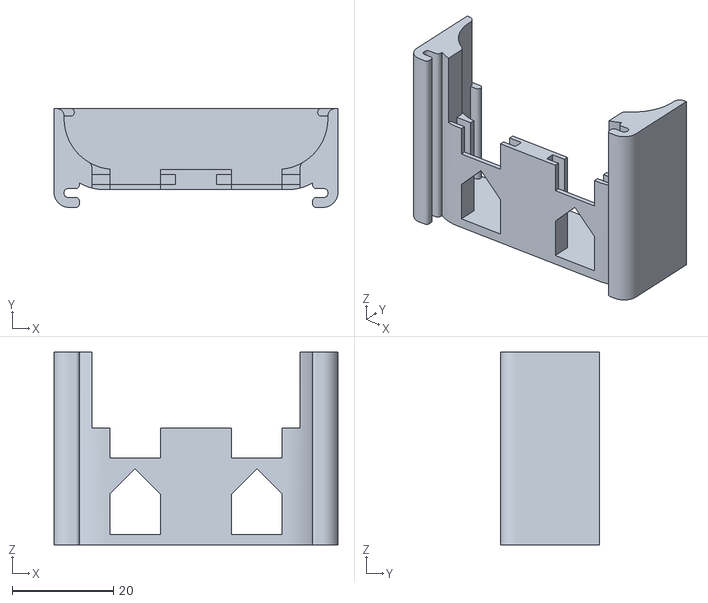
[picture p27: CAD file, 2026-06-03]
mechanics/base_v3-base_con_placa.stl
56.0 x 19.5 x 38.0

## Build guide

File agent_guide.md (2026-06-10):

# Guía de Operación y Procesamiento para Agentes Futuros (ORR)

Esta guía explica el diseño experimental del sistema **Outdoor Radio Robotics (ORR)**, la estructura de los archivos de audio de medición, y el procedimiento exacto para procesar el dataset sin modificar el software del repositorio.

---

## 📻 1. Contexto del Ensayo de Campo

El sistema ORR utiliza transceptores analógicos FM (Baofeng UV-82) acoplados a microcontroladores Raspberry Pi Pico 2W. La transmisión digital se realiza usando modulación **AFSK** (1200 Hz para *Mark*/1, 2400 Hz para *Space*/0) a velocidades de 10, 50, 150, 300, 600, y 1200 baudios.

### Generación y Grabación de los Audios
1. **Transmisor (`firmware/tx`):**
   - Transmite secuencias de datos pseudoaleatorios PRBS-7 de 127 bits.
   - Para evitar dañar térmicamente el paso final de potencia RF de la radio (límite estricto de 30s de transmisión continua), las transmisiones largas se **fragmentan en ráfagas (bursts)** separadas por intervalos de enfriamiento (cooldown).
   - *10 bd:* 1 ráfaga de 127 bits (~12.7s + pre/post delay).
   - *50 bd:* 2 ráfagas de 1270 bits cada una, con 27s de enfriamiento en el medio.
   - *150 bd:* 2 ráfagas de 3175 bits cada una, con 23s de enfriamiento.
   - *300 bd:* 2 ráfagas de 6350 bits cada una, con 23s de enfriamiento.
   - *600 bd:* 1 ráfaga de 12700 bits (~21s + pre/post delay).
   - *1200 bd:* 1 ráfaga de 12700 bits (~10.5s + pre/post delay).

2. **Receptor (`firmware/rx`):**
   - El receptor corre una interfaz Web-DAQ en el navegador móvil del operador.
   - Graba de forma **continua** todo el audio de la sesión (incluidos silencios, ruido de squelch, y múltiples ráfagas) y genera un único archivo `.wav` principal (ej. `audio_sdr_20260604_172447.wav`).

---

## 🎧 2. Archivos de Ráfagas (`_burst_X.wav`) vs. Archivos Principales

Dado que la grabación es continua, el archivo `.wav` principal contiene el ruido de fondo, silencios de cooldown, y todas las ráfagas transmitidas en la sesión.

- **`audio_sdr_*.wav` (Principal con ráfagas asociadas):** Contiene la sesión completa. Si intentamos procesar este archivo con la suite de demodulación, el analizador espectral detectará y se centrará únicamente en la *primera ráfaga*, ignorando las siguientes y duplicando el análisis de la primera ráfaga.
- **`audio_sdr_*_burst_X.wav` (Ráfagas individuales):** Son segmentos de audio pre-extraídos que contienen estrictamente la ráfaga `X` de la sesión. Estos deben procesarse individualmente para evaluar el desempeño (BER y Confianza) de cada ráfaga de forma aislada.
- **`audio_sdr_*.wav` (Principal SIN ráfagas asociadas):** Sesiones de transmisión que constan de una única ráfaga (como a 10 bd o 1200 bd), donde no se requería fragmentación o no se extrajeron ráfagas separadas. Estos archivos principales deben ser procesados directamente.

---

## ⚡ 3. Procedimiento de Filtrado y Ejecución Paso a Paso

Para procesar el dataset respetando la lógica descrita y sin alterar el código del repositorio, se utiliza una técnica de filtrado por directorios temporales:

### Paso A: Crear un directorio de entrada filtrado
Creamos un directorio temporal `data_filtered` y copiamos únicamente los archivos requeridos:
1. Copiar todos los archivos que contengan `_burst_` en su nombre (junto con sus metadatos `.csv`).
2. Copiar los archivos `.wav` y `.csv` principales que **no tengan** ningún archivo de ráfaga asociado en el directorio original.

Ejemplo en Bash para procesar la distancia de `5` metros:
```bash
# Limpiar y preparar carpeta temporal
mkdir -p data_filtered/5

# 1. Copiar todos los archivos de ráfaga (wav y csv correspondientes)
cp data/libre/5/*_burst_*.wav data_filtered/5/
for f in data_filtered/5/*_burst_*.wav; do
    # Obtener el nombre base del csv de metadatos (el csv original se llama igual que el wav principal)
    base=$(echo $(basename $f) | sed 's/_burst_.*//')
    cp data/libre/5/${base}.csv data_filtered/5/$(basename $f .wav).csv
done

# 2. Copiar los archivos principales que no tienen ráfagas
for f in data/libre/5/audio_sdr_*.wav; do
    if [[ ! "$f" =~ _burst_ ]]; then
        base=$(basename $f .wav)
        # Si no existe ningún archivo de ráfaga para este base, copiar el principal
        if ! ls data/libre/5/${base}_burst_* 1>/dev/null 2>&1; then
            cp data/libre/5/${base}.wav data_filtered/5/
            cp data/libre/5/${base}.csv data_filtered/5/
        fi
    fi
done
```

### Paso B: Ejecutar la Suite de Demodulación
Una vez preparada la carpeta temporal con los archivos de entrada correctos, se ejecuta la suite original de procesamiento:
```bash
python3 ORR/processing/run_suite.py data_filtered/5
```

Este procedimiento garantiza que la suite de demodulación se ejecute sobre los archivos correctos sin duplicar datos y procesando todas las ráfagas individuales disponibles.

---

## 📊 4. Generación del CSV de Resultados (`generate_csv.py`)

Para consolidar los resultados obtenidos por la suite de demodulación, se utiliza el script [generate_csv.py](file:///home/seba/Dropbox/1_UNSJ/1_proyectos_investigacion/intercomunicador/antigravity/arreglando_orr/ORR/processing/generate_csv.py). Este script automatiza la correlación de los archivos de audio procesados con sus correspondientes datos de telemetría GPS para calcular las distancias reales y calcular el BER acumulado por sesión.

### Flujo de Ejecución de 3 Etapas

El pipeline de procesamiento completo se ejecuta de forma independiente y auditable en las siguientes etapas:

1. **Segmentación (`generate_bursts.py`):**
   ```bash
   python3 ORR/processing/generate_bursts.py data/libre/ -o data_generated/libre/ --grid
   ```
2. **Demodulación (`run_suite.py`):**
   ```bash
   python3 ORR/processing/run_suite.py data_generated/libre/ > salida_libre.txt
   ```
3. **Consolidación (`generate_csv.py`):**
   ```bash
   python3 ORR/processing/generate_csv.py -i salida_libre.txt -d data_generated/libre/ -o resultado_libre.csv
   ```

### Parámetros de `generate_csv.py`

- `-i`, `--input`: Ruta al archivo de texto con la salida de `run_suite.py` (obligatorio).
- `-d`, `--dir`: Ruta al directorio que contiene las ráfagas generadas con sus metadatos GPS en formato `.csv` (obligatorio).
- `-o`, `--output`: Ruta de salida para el archivo `.csv` estructurado (obligatorio).
- `-t`, `--threshold`: Umbral en metros para segmentar sesiones (opcional). Si se omite, se calcula automáticamente usando la media más dos desviaciones estándar de los saltos de distancia.

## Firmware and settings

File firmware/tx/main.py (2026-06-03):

"""
main.py — Orquestador de la Máquina de Estados (FSM) y Gestión de Transmisión
============================================================================
Proyecto : Comunicación Digital sobre Radios Analógicas FM (JAR 2026)
Instituto: Instituto de Automática (INAUT) — UNSJ — CONICET
Hardware : Raspberry Pi Pico 2W (RP2350) + Baofeng UV-82

Este es el script de entrada (main) del transmisor optimizado para campo.
Se han eliminado por completo los reportes detallados por el puerto USB-UART
para maximizar la velocidad de ejecución del lazo y evitar el uso de buffers
de transmisión serie innecesarios, garantizando un funcionamiento silencioso.
============================================================================
"""

import time
import gc
import config
from hal import HAL
from lfsr import LFSR
from modulator import AFSKModulator


# Definición de Estados de la FSM
STATE_IDLE         = 0
STATE_PTT_ON       = 1
STATE_TRANSMIT     = 2
STATE_PTT_OFF      = 3
STATE_COOLDOWN     = 4
STATE_COMPLETED    = 5
STATE_PRE_WAIT     = 6


def debug_log(tag, message):
    """
    Imprime mensajes de depuración formateados a través del puerto serie
    si la bandera DEBUG en config.py está activa.
    """
    if config.DEBUG:
        # Formateo ordenado y tabulado de tags para Thonny
        print("[{:8s}] {}".format(tag, message))

def led_blink_pattern(hal, pattern_type):
    """
    Patrones de destello de LED para interactuar de forma intuitiva con el operador.
    """
    if pattern_type == "boot":
        # Parpadeo triple rápido al iniciar
        for _ in range(3):
            hal.set_led(True)
            time.sleep_ms(100)
            hal.set_led(False)
            time.sleep_ms(100)
    elif pattern_type == "session_complete":
        # Parpadeo rápido sostenido al terminar la sesión completa de 12700 bits
        for _ in range(5):
            hal.set_led(True)
            time.sleep_ms(50)
            hal.set_led(False)
            time.sleep_ms(50)

def main():
    # Inicializar Abstracciones de Hardware y Algoritmos
    hal = HAL()

    # Indicar arranque exitoso con parpadeo físico INMEDIATAMENTE
    # Esto asegura retroalimentación visual al resetear con batería, antes de cualquier print serie.
    led_blink_pattern(hal, "boot")

    lfsr = LFSR()
    modulator = AFSKModulator(table_size=config.TABLE_SIZE)

    # Mostrar arranque exitoso e informar al operador
    debug_log("SISTEMA", "=== INICIANDO TRANSMISOR AFSK (RP2350) ===")
    debug_log("SISTEMA", "Pines de hardware: PWM_TX=GP{}, PTT=GP{}, TRIGGER=GP{}".format(
        config.PIN_PWM_TX, config.PIN_PTT, config.PIN_TRIGGER
    ))
    debug_log("SISTEMA", "Parámetros AFSK: Mark={} Hz, Space={} Hz | Muestreo (Fs)={} Hz".format(
        config.F_MARK, config.F_SPACE, config.FS
    ))
    debug_log("SISTEMA", "Trama de velocidades cíclicas (Baudios): {}".format(config.BAUD_RATES))

    # Generar secuencia binaria pseudoaleatoria patrón PRBS-7
    prbs_seq = lfsr.generate_sequence()
    debug_log("PRBS-7", "Secuencia PRBS-7 generada (127 bits).")
    debug_log("PRBS-7", " - Balance: {} unos (1s), {} ceros (0s)".format(
        sum(prbs_seq), len(prbs_seq) - sum(prbs_seq)
    ))

    # Variables de control de velocidad y de estados de la FSM
    current_baud_idx = 0
    fsm_state = STATE_IDLE
    
    session_baud = config.BAUD_RATES[current_baud_idx]
    bursts_total = 0
    burst_current = 0
    burst_bits_list = []
    
    # Registros para cálculos térmicos y control
    t_tx_start = 0
    t_tx_real = 0
    t_cooldown_start = 0
    t_cooldown_duration = 0
    
    # Variable para controlar la cuenta regresiva periódica en Thonny
    last_cooldown_sec_printed = -1

    # Variables para el control de la cuenta regresiva de pre-espera (caminata)
    pre_wait_start = 0
    last_minute_processed = -1
    last_second_printed = -1

    debug_log("FSM", "Estado: IDLE. Esperando flanco GP2 (gatillo)...")

    # Variable para monitorear el tiempo de pulsación del botón GP2
    button_press_start = None

    try:
        while True:
            # --- SISTEMA DE REINICIO POR SOFTWARE MEDIANTE GATILLO (Pulsación de 3 segundos) ---
            # Solo se verifica en estados no críticos de modulación (fuera de STATE_TRANSMIT)
            if fsm_state != STATE_TRANSMIT:
                if hal.trigger.value() == 0:  # Botón presionado (activo en BAJO)
                    if button_press_start is None:
                        button_press_start = time.ticks_ms()
                    else:
                        elapsed = time.ticks_diff(time.ticks_ms(), button_press_start)
                        if elapsed > 3000:  # 3 segundos
                            debug_log("SISTEMA", "¡REINICIO DE SOFTWARE INICIADO POR EL OPERADOR (Pulsación larga GP2)!")
                            # Patrón de advertencia visual rápido en el LED
                            for _ in range(15):
                                hal.set_led(True)
                                time.sleep_ms(40)
                                hal.set_led(False)
                                time.sleep_ms(40)
                            import machine
                            machine.reset()
                else:
                    button_press_start = None
            # ========================================================================
            #  ESTADO: IDLE (Reposo y Monitoreo del Gatillo GP2)
            # ========================================================================
            if fsm_state == STATE_IDLE:
                if hal.check_trigger_rising_edge():
                    if config.AUTONOMOUS_MODE:
                        debug_log("GATILLO", "¡Gatillo detectado! Modo AUTÓNOMO activo.")
                        debug_log("GATILLO", " - Iniciando cuenta regresiva de pre-espera: {} minutos".format(config.PRE_WAIT_MINUTES))
                        
                        pre_wait_start = time.ticks_ms()
                        last_minute_processed = -1
                        last_second_printed = -1
                        fsm_state = STATE_PRE_WAIT
                    else:
                        # Modo Laboratorio: Iniciar transmisión inmediata de la velocidad actual
                        session_baud = config.BAUD_RATES[current_baud_idx]
                        frag_info = config.FRAGMENTATION[session_baud]
                        
                        burst_bits = frag_info["burst_bits"]
                        bursts_total = frag_info["bursts"]
                        
                        debug_log("GATILLO", "¡Gatillo detectado! Modo LABORATORIO activo (inmediato).")
                        debug_log("GATILLO", " - Velocidad de ensayo: {} baudios".format(session_baud))
                        debug_log("GATILLO", " - Plan de ráfagas: {} bursts de {} bits".format(bursts_total, burst_bits))
                        
                        # Preparar los bits para la ráfaga repitiendo la secuencia PRBS-7
                        repetitions = burst_bits // len(prbs_seq)
                        burst_bits_list = prbs_seq * repetitions
                        
                        burst_current = 0
                        fsm_state = STATE_PTT_ON


            # ========================================================================
            #  ESTADO: PRE_WAIT (Cuenta Regresiva y Emisión de Tonos de Presencia)
            # ========================================================================
            elif fsm_state == STATE_PRE_WAIT:
                # Calcular el tiempo transcurrido en segundos
                elapsed_ms = time.ticks_diff(time.ticks_ms(), pre_wait_start)
                elapsed_s = elapsed_ms // 1000
                total_wait_s = config.PRE_WAIT_MINUTES * 60
                
                if elapsed_s >= total_wait_s:
                    debug_log("PRE-WAIT", "¡Cuenta regresiva de pre-espera finalizada con éxito!")
                    
                    # Preparar los parámetros de transmisión para la primera ráfaga
                    session_baud = config.BAUD_RATES[current_baud_idx]
                    frag_info = config.FRAGMENTATION[session_baud]
                    burst_bits = frag_info["burst_bits"]
                    bursts_total = frag_info["bursts"]
                    
                    debug_log("TX_START", "Iniciando transmisión de ensayo a {} baudios.".format(session_baud))
                    debug_log("TX_START", " - Plan de ráfagas: {} bursts de {} bits".format(bursts_total, burst_bits))
                    
                    # Preparar los bits repitiendo la secuencia PRBS-7
                    repetitions = burst_bits // len(prbs_seq)
                    burst_bits_list = prbs_seq * repetitions
                    
                    burst_current = 0
                    fsm_state = STATE_PTT_ON
                else:
                    # Mostrar cuenta regresiva de forma ordenada segundo a segundo
                    remaining_s = total_wait_s - elapsed_s
                    if remaining_s != last_second_printed:
                        rem_min = remaining_s // 60
                        rem_sec = remaining_s % 60
                        debug_log("PRE-WAIT", "Tiempo para la transmisión: {:02d}:{:02d}".format(rem_min, rem_sec))
                        last_second_printed = remaining_s
                    
                    # Hacer parpadear el LED lentamente para indicar estado ocupado en pre-espera
                    # Ciclo de 1000 ms: encendido 100 ms, apagado 900 ms
                    cycle_pos = elapsed_ms % 1000
                    if cycle_pos < 100:
                        hal.set_led(True)
                    else:
                        hal.set_led(False)
                    
                    # Determinar minuto y segundo actual
                    m = elapsed_s // 60
                    sec_in_min = elapsed_s % 60
                    
                    # En el segundo 55 del minuto actual (salvo el último minuto), emitir aviso de 3s
                    if m < config.PRE_WAIT_MINUTES - 1 and sec_in_min == 55:
                        if last_minute_processed != m:
                            last_minute_processed = m
                            remaining_minutes = config.PRE_WAIT_MINUTES - 1 - m
                            
                            debug_log("PRE-WAIT", "Emitiendo aviso del minuto {} (Faltan {} minutos)...".format(m + 1, remaining_minutes))
                            
                            # Decidir si mandar el patrón pre-anuncio o el tono puro de 2400 Hz
                            if remaining_minutes == 2 or remaining_minutes == 1:
                                debug_log("PRE-WAIT", " -> Mandando patrón pre-anuncio 01010101 (3s)...")
                                bits_to_send = [0, 1] * 1800  # 3 segundos a 1200 baudios
                            else:
                                debug_log("PRE-WAIT", " -> Mandando tono de presencia 2400 Hz (3s)...")
                                bits_to_send = [0] * 3600  # 3 segundos a 1200 baudios
                            
                            # Realizar transmisión síncrona
                            hal.set_led(True)
                            hal.set_ptt(True)
                            time.sleep_ms(config.PTT_PRE_DELAY_MS)
                            
                            try:
                                modulator.transmit_burst(
                                    bits=bits_to_send,
                                    baud_rate=1200,
                                    fs=config.FS,
                                    f_mark=config.F_MARK,
                                    f_space=config.F_SPACE,
                                    pwm_device=hal.pwm
                                )
                            except Exception as e:
                                debug_log("PRE-WAIT ERROR", "Falla en transmisión de tono: {}".format(e))
                            
                            hal.silence_pwm()
                            time.sleep_ms(config.PTT_POST_DELAY_MS)
                            hal.set_ptt(False)
                            hal.set_led(False)
                            
                            debug_log("PRE-WAIT", "Aviso del minuto {} emitido de forma segura.".format(m + 1))

            # ========================================================================
            #  ESTADO: PTT_ON (Estabilización de Portadora RF)
            # ========================================================================
            elif fsm_state == STATE_PTT_ON:
                debug_log("PTT", "Activando PTT de radio Baofeng y LED indicador...")
                hal.set_led(True)     # LED encendido fijo durante transmisión
                hal.set_ptt(True)     # Activar PTT mediante optoacoplador PC817
                
                # Esperar retardo de apertura del squelch
                debug_log("PTT", "Esperando estabilización de portadora pre-TX ({} ms)...".format(config.PTT_PRE_DELAY_MS))
                time.sleep_ms(config.PTT_PRE_DELAY_MS)
                fsm_state = STATE_TRANSMIT

            # ========================================================================
            #  ESTADO: TRANSMIT (Síntesis Digital CPFSK en Lazo Crítico)
            # ========================================================================
            elif fsm_state == STATE_TRANSMIT:
                debug_log("TX", "Modulando ráfaga {}/{} ({} bits)...".format(
                    burst_current + 1, bursts_total, len(burst_bits_list)
                ))
                t_tx_start = time.ticks_ms()
                
                tx_aborted = False
                try:
                    # Iniciar lazo crítico de modulación sin jitter
                    modulator.transmit_burst(
                        bits=burst_bits_list,
                        baud_rate=session_baud,
                        fs=config.FS,
                        f_mark=config.F_MARK,
                        f_space=config.F_SPACE,
                        pwm_device=hal.pwm
                    )
                except RuntimeError as e:
                    if str(e) == "TIMEOUT_PROTECTION_PA":
                        debug_log("CRÍTICO", "¡ALERTA TÉRMICA! Transmisión abortada por watchdog por superar los {}s.".format(config.MAX_TX_TIME_S))
                        tx_aborted = True
                    else:
                        raise e
                
                hal.silence_pwm()
                t_tx_real = time.ticks_diff(time.ticks_ms(), t_tx_start)
                if tx_aborted:
                    debug_log("TX", "Transmisión ABORTADA por seguridad a los {} ms.".format(t_tx_real))
                else:
                    debug_log("TX", "Ráfaga modulada exitosamente en {} ms (teórico: {} ms)".format(
                        t_tx_real, int((len(burst_bits_list) * 1000) / session_baud)
                    ))
                fsm_state = STATE_PTT_OFF

            # ========================================================================
            #  ESTADO: PTT_OFF (Apagado Seguro del Transmisor)
            # ========================================================================
            elif fsm_state == STATE_PTT_OFF:
                debug_log("PTT", "Esperando retardo de cola post-TX ({} ms) para propagar audio...".format(config.PTT_POST_DELAY_MS))
                # Retardo de cola para que se propaguen las últimas muestras de audio
                time.sleep_ms(config.PTT_POST_DELAY_MS)
                
                hal.set_ptt(False)
                hal.set_led(False)
                debug_log("PTT", "PTT y LED apagados de forma segura.")
                
                # Cálculo de enfriamiento proporcional
                t_ptt_activo_ms = t_tx_real + config.PTT_PRE_DELAY_MS + config.PTT_POST_DELAY_MS
                t_cooldown_prop = int(config.COOLDOWN_RATIO * t_ptt_activo_ms)
                
                # Pausa mínima de enfriamiento del ensayo según la velocidad
                frag_info = config.FRAGMENTATION[session_baud]
                t_cooldown_min_ensayo = frag_info["min_cooldown_s"] * 1000
                
                # Selección del peor caso para máxima seguridad térmica del PA
                t_cooldown_duration = max(
                    t_cooldown_prop, 
                    t_cooldown_min_ensayo, 
                    config.COOLDOWN_MIN_MS
                )
                
                debug_log("TÉRMICO", "Análisis de tiempo de enfriamiento:")
                debug_log("TÉRMICO", " - Ciclo de trabajo proporcional (50%): {} ms".format(t_cooldown_prop))
                debug_log("TÉRMICO", " - Mínimo para metodología de ensayo: {} ms".format(t_cooldown_min_ensayo))
                debug_log("TÉRMICO", " - Mínimo absoluto de protección:      {} ms".format(config.COOLDOWN_MIN_MS))
                debug_log("TÉRMICO", " -> Enfriamiento total requerido:      {:.2f} s".format(t_cooldown_duration / 1000.0))
                
                t_cooldown_start = time.ticks_ms()
                last_cooldown_sec_printed = -1
                fsm_state = STATE_COOLDOWN

            # ========================================================================
            #  ESTADO: COOLDOWN (Mitigación Térmica Obligatoria)
            # ========================================================================
            elif fsm_state == STATE_COOLDOWN:
                elapsed = time.ticks_diff(time.ticks_ms(), t_cooldown_start)
                remaining = t_cooldown_duration - elapsed
                
                if remaining > 0:
                    # Reportar el tiempo de cooldown segundo a segundo en Thonny
                    remaining_s = int(remaining / 1000) + 1
                    if remaining_s != last_cooldown_sec_printed:
                        debug_log("TÉRMICO", "Enfriando PA de radio... Quedan {} segundos...".format(remaining_s))
                        last_cooldown_sec_printed = remaining_s

                    # Hacer parpadear el LED lentamente para notificar el estado ocupado
                    hal.set_led(True)
                    time.sleep_ms(250)
                    hal.set_led(False)
                    time.sleep_ms(250)
                else:
                    debug_log("TÉRMICO", "¡Ciclo de enfriamiento completado!")
                    burst_current += 1
                    if burst_current < bursts_total:
                        debug_log("FSM", "Iniciando ráfaga programada número {}...".format(burst_current + 1))
                        fsm_state = STATE_PTT_ON
                    else:
                        debug_log("FSM", "Ensayo a {} baudios completado para la sesión de 12700 bits.".format(session_baud))
                        # Sesión de ensayo a esta velocidad completada
                        led_blink_pattern(hal, "session_complete")
                        
                        # ¿Es el último baudrate de la lista de velocidades ensayadas?
                        if current_baud_idx == len(config.BAUD_RATES) - 1:
                            debug_log("FSM", "¡SECUENCIA DE TODOS LOS BAUDRATES COMPLETADA CON ÉXITO!")
                            debug_log("FSM", "Bloqueando inicio de nuevos ensayos. Mantenga presionado GP2 por >3s para reiniciar.")
                            fsm_state = STATE_COMPLETED
                        else:
                            if config.AUTONOMOUS_MODE:
                                # Avanzar automáticamente al siguiente baudrate de la lista de velocidades
                                current_baud_idx += 1
                                session_baud = config.BAUD_RATES[current_baud_idx]
                                frag_info = config.FRAGMENTATION[session_baud]
                                
                                burst_bits = frag_info["burst_bits"]
                                bursts_total = frag_info["bursts"]
                                
                                debug_log("FSM", "Avanzando automáticamente al siguiente ensayo: {} baudios".format(session_baud))
                                debug_log("FSM", " - Plan de ráfagas: {} bursts de {} bits".format(bursts_total, burst_bits))
                                
                                # Preparar los bits para la ráfaga de la nueva velocidad
                                repetitions = burst_bits // len(prbs_seq)
                                burst_bits_list = prbs_seq * repetitions
                                
                                burst_current = 0
                                # Transicionar directamente a PTT_ON para iniciar la modulación de forma autónoma
                                fsm_state = STATE_PTT_ON
                            else:
                                # Modo laboratorio: rotar cíclicamente y esperar gatillazo en IDLE para el siguiente ensayo
                                current_baud_idx = (current_baud_idx + 1) % len(config.BAUD_RATES)
                                next_baud = config.BAUD_RATES[current_baud_idx]
                                debug_log("FSM", "Rotación de velocidad: Próximo ensayo se transmitirá a {} baudios.".format(next_baud))
                                
                                debug_log("FSM", "Estado: IDLE. Listo y esperando gatillazo en GP2...")
                                fsm_state = STATE_IDLE
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

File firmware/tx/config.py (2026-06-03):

"""
config.py — Parámetros Centralizados del Sistema Transmisor AFSK
============================================================================
Proyecto : Comunicación Digital sobre Radios Analógicas FM (JAR 2026)
Instituto: Instituto de Automática (INAUT) — UNSJ — CONICET
Hardware : Raspberry Pi Pico 2W (RP2350) + Baofeng UV-82

Este módulo contiene todos los parámetros de configuración del sistema,
adaptados rigurosamente de la "Metodología Experimental" (metodologia_experimental.md).
============================================================================
"""

# ============================================================================
#  CONTROL DE DEPURACIÓN (DIAGNÓSTICO EN PC/THONNY)
# ============================================================================
DEBUG = True  # True para ver reportes en Thonny, False para optimización en campo

# ============================================================================
#  PARÁMETROS DE MODULACIÓN AFSK
# ============================================================================

# Frecuencias de tono AFSK (Hz) - Propuesta A (Ortogonal y Fase Sincrónica)
# Mark (bit lógico 1) y Space (bit lógico 0)
F_MARK  = 1200   # Hz — Tono para bit '1' (Exactamente 1.0 ciclo entero a 1200 bd)
F_SPACE = 2400   # Hz — Tono para bit '0' (Exactamente 2.0 ciclos enteros a 1200 bd)

# Velocidades de transmisión a ensayar (baudios)
# Cada pulsación del gatillo iniciará la transmisión en la siguiente velocidad,
# rotando de forma cíclica: 10 -> 50 -> 150 -> 300 -> 600 -> 1200
BAUD_RATES = [10, 50, 150, 300, 600, 1200]

# Frecuencia de muestreo del sintetizador de audio (Hz)
# Elevado a 19200 Hz para duplicar la resolución de la forma de onda
# y desplazar las espurias de muestreo digital fuera de la banda de audio.
# Divide de manera exacta a todas las velocidades de prueba:
#   19200 / 10   = 1920 muestras/bit
#   19200 / 50   = 384 muestras/bit
#   19200 / 150  = 128 muestras/bit
#   19200 / 300  = 64 muestras/bit
#   19200 / 600  = 32 muestras/bit
#   19200 / 1200 = 16 muestras/bit
FS = 19200  # Hz

# Frecuencia de la portadora PWM de hardware (Hz)
# Se utiliza 125 kHz para que la componente de conmutación esté muy alejada de la
# banda de voz. El atenuador resistivo de TX (10 kΩ serie + 1 kΩ shunt) reduce la
# señal de 3.3Vp-p a ~300mVp-p, y el capacitor de 47 µF acopla en serie la señal
# de audio bloqueando la continua, delegando el filtrado del portador PWM al ancho
# de banda extremadamente acotado del propio preamplificador de micrófono de la radio.
F_PWM = 125_000  # Hz

# Tamaño de la tabla de onda senoidal para síntesis digital directa (DDS)
TABLE_SIZE = 256

# ============================================================================
#  MAPEO DE PINES DE HARDWARE (RP2350)
# ============================================================================
PIN_PWM_TX  = 17     # GP17 (Pin físico 22) — Salida de audio PWM
PIN_PTT     = 16     # GP16 (Pin físico 21) — Control PTT (Optoacoplador PC817)
PIN_TRIGGER = 2      # GP2  (Pin físico 4)  — Pulsador de gatillo (con pull-up activa)
PIN_LED     = "LED"  # LED integrado para retroalimentación visual

# ============================================================================
#  TEMPORIZACIÓN Y CONFIGURACIÓN DE PTT
# ============================================================================
PTT_PRE_DELAY_MS  = 1000   # Retardo para apertura de squelch en receptor (ms)
PTT_POST_DELAY_MS = 1000  # Retardo de cola para propagación completa de muestras (ms)

# Habilita el modo de ensayo autónomo de campo (manos libres).
# - True: Cuenta regresiva de 10 min, tonos cada minuto, transmisión y avance de velocidades automático.
# - False: Sin espera, sin tonos, y cada velocidad requiere presionar GP2 manualmente (modo laboratorio/depuración).
AUTONOMOUS_MODE = True

# Tiempo de espera autónomo antes de la transmisión (minutos)
# Permite al operador caminar hasta su destino antes de iniciar la modulación de la trama.
# Cada minuto se enviará un tono/anuncio de 3s para retroalimentación en campo.
PRE_WAIT_MINUTES = 3



# ============================================================================
#  PROTECCIÓN TÉRMICA DE LA PORTADORA (Baofeng UV-82) Y GESTIÓN DE FRAGMENTACIÓN
# ============================================================================

# Volumen de datos total requerido por punto de ensayo para consistencia estadística
# Volumen de datos total requerido por punto de ensayo para consistencia estadística
# Nota: Modificado para velocidades lentas (50 bd y 150 bd) para evitar cuellos de botella térmicos
TOTAL_TEST_BITS = 12700  # 100 ciclos completos de la PRBS-7 (127 bits) de referencia

# Límite máximo de transmisión continua por ráfaga (segundos) - Optimización Térmica y de Batería
MAX_TX_TIME_S = 30  # Límite estricto de 30 segundos por ráfaga para proteger el PA de la radio
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

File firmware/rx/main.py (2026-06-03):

import machine
import config
import red_wifi
import servidor_web
import indicador_led

def main():
    print("=========================================")
    print("  Receptor Web-DAQ SDR - INAUT (UNSJ)    ")
    print("=========================================")
    
    # 0. Overclocking seguro del microcontrolador a 150 MHz 
    # (Por defecto RP2040/RP2350 está a 125/150, forzamos 150MHz
    #  para garantizar que el WiFi TCP no interfiera con el Timer del ADC).
    machine.freq(150000000)
    
    # Activar parpadeo medio: alimentación conectada, buscando red/cliente
    indicador_led.establecer_estado('esperando')
    
    # 1. Levantar la red Wi-Fi
    ap, ip = red_wifi.configurar_ap(config.WIFI_SSID, config.WIFI_PASS, config.WIFI_IP)
    
    print(f"\n[INFO] 📱 Conéctate a la red Wi-Fi: '{config.WIFI_SSID}'")
    print(f"[INFO] 🌍 Abre en el navegador del celular: http://{ip}")
    print("-----------------------------------------")
    
    # 2. Entrar al loop infinito del servidor Web-DAQ
    servidor_web.iniciar_servidor(config.WEB_PORT)

if __name__ == '__main__':
    main()

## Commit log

2026-06-03 chore: add .gitignore and stop tracking csv and pyc files
    [audio_sdr_20260523_192644.csv, audio_sdr_20260523_195813.csv, audio_sdr_20260524_112436.csv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]
2026-06-07 refact: se modifica detector_baudios.py para usar búsqueda de fase y rate en cuadratura
2026-06-07 refact: se modifican comentarios y se remueve lista de audios de prueba en config.py
2026-06-07 refact: se remueven adjetivos subjetivos en comentarios de analizador_espectral.py
2026-06-07 refact: se eliminan calificaciones de calidad en los comentarios de la clase DPLL
2026-06-07 refact: se integra autodetección dinámica y búsqueda de fase por ráfaga en run_suite.py
2026-06-07 docs: actualizar README principal con el demodulador por envolventes y busqueda de fase
2026-06-07 docs: actualizar README de procesamiento con el flujo de filtros Butterworth y guia CLI
2026-06-07 Añade flags de verbosidad e imágenes en run_suite.py
2026-06-07 Imprime resultados inmediatos en run_suite.py de forma compacta
2026-06-07 baud_detector: limitar bits extraidos en lazo de busqueda
2026-06-07 modules/spectrum: agregar inicio y fin de bloque de rafaga a ResultadoEspectral
2026-06-07 modules/baud_detector: invertir el orden de busqueda de candidatos a baud rate
2026-06-07 refina la deteccion de la sincronizacion para bajar el BER.
2026-06-08 Add generate_bursts.py script for automatic AFSK burst segmentation using bandpass filtering, RMS thresholding, and grid search
2026-06-08 docs(data): expand experimental dataset documentation and correct frequency to 433 MHz UHF
    Detailed changes:
    - Added direct link to the Google Drive shared folder hosting the raw WAV database.
    - Documented database structure: 'campo/' (field test in olive grove) and 'libre/' (line-of-sight/lab tests at 5m, 500m, 1000m, and 1500m).
    - Detailed the file naming convention audio_sdr_YYYYMMDD_HHMMSS.[wav|csv] and the biunique indexation between audio and GPS telemetry.
    - Described the receiver (RX) Web-DAQ architecture, detailing Core 1 ADC sampling (19200 Hz, dual-buffer ping-pong, 16-bit signed PCM) and Core 0 Wi-Fi AP streaming.
    - Described the transmitter (TX) Capa Física, detailing the Fibon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
2026-06-09 fix(generate_bursts): reemplazar detección por energía con validación por patrón de protocolo
    El detector anterior usaba solo un umbral de energía RMS, lo que generaba
    falsos positivos cuando el audio contenía ruido de canal similar en potencia
    a las ráfagas AFSK (ej. audio_sdr_20260606_141943 con 2 bursts incorrectos).
    Nueva lógica en es_bloque_afsk_valido():
    - Validación de duración: compara contra las duraciones del protocolo
    (10.58s, 12.7s, 21.17s, 25.4s) con tolerancia ±2s
    - Validación de secuencia de portadora silenciosa: verifica que la
    potencia RMS del segmento activo sea al menos 2.5× mayor que el
    pre-padding y post-padding de 1s (según PTT_PRE/POST_DE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
2026-06-09 fix(baud_detector): eliminar hardcode N_s=16.0236 para 1200 bd — usar cálculo dinámico fs/baud
    El período de símbolo N_s se calculaba con un valor hardcodeado (16.0236 muestras)
    exclusivamente para 1200 baudios, asumiendo un drift de reloj fijo del transmisor.
    Esto era incorrecto conceptualmente: el drift real varía entre transmisores y
    condiciones de RF. El DPLL es quien debe compensar ese drift, no N_s.
    Se reemplaza el bloque condicional por una sola línea dinámica:
    N_s = float(self.fs / baud)
    Esto mantiene la coherencia matemática con el resto del pipeline y delega
    la adaptación al drift al lazo DPLL sintonizable por grilla.
2026-06-09 feat(config): ampliar grilla de candidatos DPLL para mejorar tracking a 1200 bd
    Los candidatos previos de Kp (máx 0.25) y Ki (máx 0.008) resultaban insuficientes
    para seguir el drift de reloj del transmisor a 1200 baudios, donde el período de
    símbolo es de solo ~16 muestras.
    Se agregan valores más agresivos:
    DPLL_KP_CANDIDATOS: ahora incluye 0.35 y 0.50
    DPLL_KI_CANDIDATOS: ahora incluye 0.015
    Esto amplía el espacio de búsqueda del grid search sin romper la convergencia
    para velocidades más bajas (10–600 bd), donde Kp pequeño sigue siendo candidato.
    [config.py]
2026-06-09 feat(run_suite): pipeline especializado 1200 bd con filtfilt zero-phase, normalización geométrica y squelch de inicio
    Problema raíz detectado: el detector de envolventes con lfilter introducía ~8.8
    muestras de retardo de grupo a 1200 bd (LP a 900 Hz), causando ISI sistemático
    en transiciones hacia rachas largas (ej. 010000...0 o 101111...1).
    Cambios principales:
    ━━━━━━━━━━━━━━━━━━━━━━━━━━━━━━━━━━━━━━━━━━━━━━━━━━━━━━━━━━━━━━━━━━━━
    1. FILTRADO ZERO-PHASE PARA 1200 bd:
    Se bifurca el pipeline: para baud_rate == 1200 se usa signal.filtfilt()
    (fase nu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
2026-06-09 docs(processing/README): documentar bifurcación del pipeline para 1200 bd
    El README describía un pipeline lineal genérico de 6 pasos que ya no refleja
    la implementación actual. Se actualizan el diagrama ASCII y las descripciones
    para documentar los cambios introducidos en run_suite.py:
    - Diagrama bifurcado: rama 1200 bd (filtfilt zero-phase + norm. geométrica
    + squelch de inicio) vs. rama ≤ 600 bd (lfilter causal clásico).
    - Paso 3: explica la razón del split (retardo de grupo de ~8.8 muestras
    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
2026-06-09 docs(README): actualizar sección técnica del demodulador para reflejar pipeline bifurcado
    La sección 'Demodulador por Envolventes Balanceadas' describía un método
    genérico sin distinguir el tratamiento especial para 1200 bd. Se reescribe
    para documentar fielmente la implementación actual:
    - Ítem nuevo 'Pipeline Bifurcado por Velocidad': describe la rama 1200 bd
    (filtfilt zero-phase, normalización geométrica, squelch de inicio) y la
    rama ≤ 600 bd (lfilter causal).
    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
2026-06-09 feat(processing): agregar generate_csv.py — generador de CSV de BER desde salida de run_suite
    Parsea la salida de texto de run_suite.py, lee telemetría GPS de los CSV de
    ráfagas, agrupa bursts en sesiones de medición usando distancia haversine con
    umbral configurable o detección automática por outliers, acumula errores y bits
    por sesión×baudrate, y escribe un CSV estructurado (Distancia_m × BER% por baudrate).
    Uso:
    python3 processing/generate_csv.py -i <salida.txt> -d <dir_bursts/> -o <resultado.csv>
    python3 processing/generate_csv.py -i <salida.txt> -d <dir_bursts/> -o <resultado.csv> -t <umbral_m>
    Los tres argumentos principales (-i, -d, -o) son obligatorios; omitir alguno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
2026-06-10 docs(processing/README): actualizar a flujo de 3 etapas y agregar documentacion de parametros y calculo de BER acumulativo de generate_csv.py
2026-06-10 docs(processing/workflow_bursts): agregar paso de consolidacion con generate_csv.py al diagrama de flujo y guia de ejecucion
2026-06-10 docs(agent_guide): agregar seccion sobre generate_csv.py y detallar el pipeline completo de 3 etapas
2026-06-14 actualizacion con la informacion del trabajo enviado a las Jornadas Argentinas de Robotica
2026-06-20 docs(fotos): agregar README con galeria de fotos experimentales
2026-06-20 docs(mechanics): agregar capturas de pantalla de los modelos 3D
2026-06-20 docs(mechanics): actualizar README con galeria de capturas de FreeCAD
2026-06-20 docs(hardware): agregar imagenes de los esquematicos
2026-10-20 agrega el documento pdf de la JAR.
2026-10-23 actualiza la foto de la radio
2026-10-23 Update README.md se sacan las referencias a las imagenes hosteadas en el repo
2026-10-26 se agrego el link de la presentacion
2026-10-26 agrega el aviso que es necesario descargar el dataset de forma manual desde google drive.
